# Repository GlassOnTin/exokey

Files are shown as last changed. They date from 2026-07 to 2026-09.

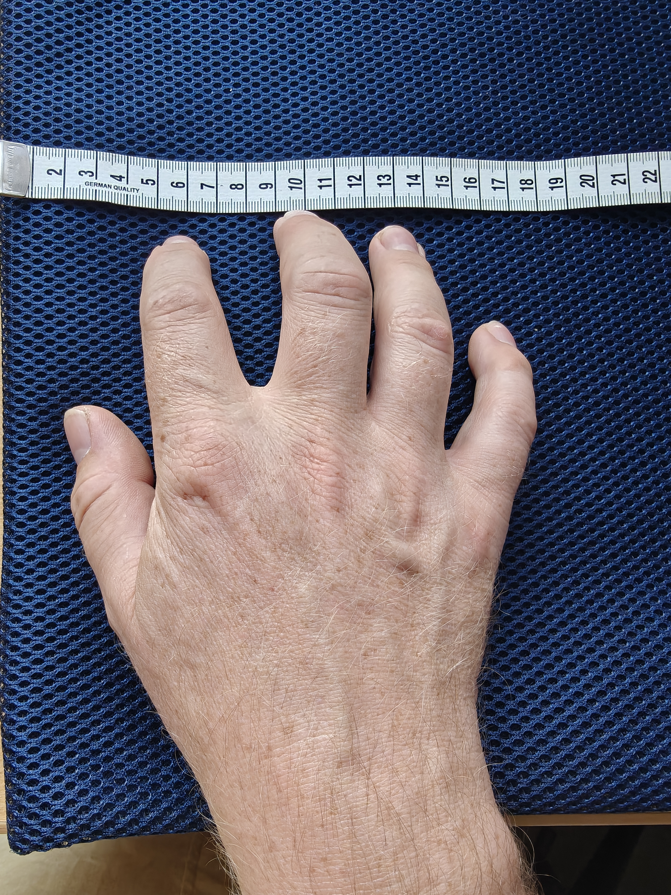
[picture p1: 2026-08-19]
docs/IMG20260819142422.jpg

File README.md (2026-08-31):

# ExoKey

**A wearable Svalboard.** One adjustable 5-way finger well per digit — each sensing five discrete directions — carried on an ultra-lightweight **carbon-fiber central dorsal spine and branching wishbone tree**, secured over the back of the hand by a soft tension strap.

It brings DataHand / Svalboard ergonomic efficiency into a walk-away wearable form factor: you can stand up, move around, and type with relaxed, natural hand postures.

---

## Interactive 3D Model & Visualizers

* **Live 3D Web Viewer:** [glassontin.github.io/exokey](https://glassontin.github.io/exokey/out/)
* **Local Interactive Assembly:** Run `PYTHONPATH=. .venv/bin/python scripts/branching_spine_view.py` and open `out/branching_spine_view.html`.
* **Documentation & Technical Guides:**
  * **[VISION.md](VISION.md)** — Architectural thesis, enabling prior art disclosures, and musculoskeletal mechanics.
  * **[docs/structural_fem.md](docs/structural_fem.md)** — Full 3D space-frame FEM formulation, load cases, and stress margins.
  * **[BUILD.md](BUILD.md)** — Fabrication, print settings, and assembly guide.
  * **[BOM.md](BOM.md)** — Bill of materials and off-the-shelf hardware list.

---

## Core Mechanical Architecture

```
                  [ DORSAL METACARPAL SADDLE ANCHOR ]
                                 │
                                 │  ◄── PRIMARY CENTRAL SPINE (⌀ 8.0 mm High-Modulus CF Tube)
                                 ▼
                        [ MIDDLE KNUCKLE ] (MCP3 4-Way Manifold Hub)
                         /              \
      TRANSVERSE ARCH   /                \  TRANSVERSE ARCH
      (⌀ 6.0 mm CF)    ▼                  ▼ (⌀ 6.0 mm CF)
                [ RING KNUCKLE ]   [ INDEX KNUCKLE ] (MCP2 Hub)
                       │                  │
      TRANSVERSE ARCH  │                  │  ◄── DIRECT 1ST WEBSPACE ARCH (⌀ 6.0 mm CF)
      (⌀ 6.0 mm CF)    ▼                  ▼
                [ LITTLE KNUCKLE ] [ THUMB KNUCKLE ] (MCP1 / TMC Hub)
                       │                  │
                       ▼                  ▼
                 [LITTLE POD]        [THUMB POD]
```

1. **Metacarpal Saddle Anchor Base:**  
   Clamps to the dorsal skeleton over the base of the 3rd metacarpal ($D = 25\text{ mm}$), securing the load path directly into the hand's rigid dorsal bridge with zero palm obstruction.
2. **Primary Central Spine:**  
   A high-modulus pultruded carbon fiber tube ($\varnothing 8.0\text{ mm}$ OD / $\varnothing 6.0\text{ mm}$ ID, $E = 180\text{ GPa}$) running along the 3rd metacarpal midline to a 4-way CNC titanium/aluminum manifold hub at the middle knuckle.
3. **Transverse Dorsal Knuckle Arch:**  
   A continuous cross-knuckle wishbone ($\varnothing 6.0\text{ mm}$ OD CF tube) spanning across `Little (MCP5) <-> Ring (MCP4) <-> Middle (MCP3) <-> Index (MCP2)` with positive daylight clearance ($> 4.0\text{ mm}$) above the skin.
4. **Direct 1st Webspace Thumb Bridge:**  
   Connects the Thumb Knuckle (MCP1/TMC) directly to the **Index Knuckle (MCP2)** across the 1st webspace, closing the structural truss and dropping thumb typing deflection by over $4\times$.
5. **Conformal 3-Link Phalanx Booms:**  
   Straight carbon fiber links ($\varnothing 5.0\text{ mm}$ OD) track the dorsal contour of each phalanx chain (`MCP -> PIP -> DIP -> Pod`) using M2.5 locking ball-collet hubs for multi-axis personal ergonomic adjustment.
6. **Svalboard 5-Way Keywells:**  
   Suspends five modular Svalboard directional switch units beneath the fingertips, capturing click, forward, back, left, and right motions with ultra-low operating force ($20\text{ gf} \approx 0.196\text{ N}$).

---

## 3D Space-Frame FEM Performance

The structure is verified using a full **3D Space-Frame Finite Element Solver** ([`structure/fem.py`](structure/fem.py)) with 6 DOFs per node ($u_x, u_y, u_z, \theta_x, \theta_y, \theta_z$):

| Digit Ray | Structural Load Path | 3D FEM Tip Deflection ($F_z = 0.20\text{ N}$) | Peak von Mises Stress | Ultimate Safety Factor |
| :--- | :--- | :---: | :---: | :---: |
| **Index** | Middle Knuckle $\rightarrow$ Arch $\rightarrow$ Index Knuckle $\rightarrow$ Booms | **$114.6\ \mu\text{m}$** | $1.87\text{ MPa}$ | **$643\times$** |
| **Middle** | Central Spine $\rightarrow$ Middle Knuckle $\rightarrow$ Booms | **$163.2\ \mu\text{m}$** | $1.93\text{ MPa}$ | **$622\times$** |
| **Ring** | Middle Knuckle $\rightarrow$ Arch $\rightarrow$ Ring Knuckle $\rightarrow$ Booms | **$135.0\ \mu\text{m}$** | $1.79\text{ MPa}$ | **$670\times$** |
| **Little** | Ring Knuckle $\rightarrow$ Arch $\rightarrow$ Little Knuckle $\rightarrow$ Booms | **$99.1\ \mu\text{m}$** | $1.72\text{ MPa}$ | **$697\times$** |
| **Thumb** | Index Knuckle $\rightarrow$ Webspace Bridge $\rightarrow$ Thumb Knuckle $\rightarrow$ Booms | **$147.9\ \mu\text{m}$** | $1.43\text{ MPa}$ | **$837\times$** |

* **Deflection Gate ($\le 200\ \mu\text{m}$):** **PASSED** (Crisp, zero-mush keyfeel)
* **Simultaneous 5-Finger Chord Typing ($1.0\text{ N}$):** Peak stress **$2.63\text{ MPa}$** (SF = $456\times$)
* **Accidental Snag / Impact Load ($2.0\text{ N}$):** Peak stress **$17.57\text{ MPa}$** (SF = $68\times$)
* **Skin Collision Clearance:** Continuous signed-distance audit confirms daylight **$\ge 1.13\text{ mm}$** everywhere (zero penetration).
* **Inter-Pod Clearance:** **$\ge 3.13\text{ mm}$** between all 10 pairwise combinations of keywell pods.

---

## Quickstart

```bash
git clone --recurse-submodules https://github.com/GlassOnTin/exokey
cd exokey
make deps          # venv + pinned dependencies
make test          # regression test suite (FEM, ball-collets, collision gates)
make view          # build and open 3D interactive HTML model
```

---

## Defensive Prior Art & Patent Preemption Declaration

**All design principles, mechanical linkages, structural load paths, and co-design algorithms documented in this repository are hereby published openly to the public domain.**

This publication constitutes prior art under 35 U.S.C. § 102 and international patent treaties (including the European Patent Convention Article 54 and PCT regulations). Specifically dedicated to the public domain to prevent patenting by third parties:
1. The **central dorsal spine backbone** anchored to a metacarpal saddle base and transmitting multi-digit typing reaction loads.
2. The **continuous transverse knuckle arch bridge** spanning across the metacarpophalangeal joints with positive skin standoff.
3. The **direct 1st-webspace index-to-thumb outrigger bridge** anchoring the thumb structure to the index knuckle.
4. The **conformal multi-link phalanx boom chain** with spherical ball-collet adjustment joints tracking finger ray ergonomics.
5. The **co-design computational optimization pipeline** coupling Hill-type musculoskeletal effort with 3D space-frame FEM structural gates.

---

## License

**[AGPL-3.0](LICENSE)** for software and firmware; **CERN-OHL-S v2** / Creative Commons **CC-BY-SA 4.0** for CAD, mechanics, and hardware documentation.

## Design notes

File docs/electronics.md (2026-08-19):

# ExoKey electronics — the read-out chain (design, not built)

> **Status.** This is the electronics *design* that the mechanical/magnetic model implies. **No
> firmware and no custom PCB exist yet**, and every magnetic figure is a prediction awaiting the
> stage-1 bench coupon ([COUPON.md](../COUPON.md)). This file writes the "no PCB yet" gap down as a
> schematic-in-words so it's a decision, not a hole. Tags: **DECIDED** vs **OPEN**.

## The chain

```
5× TLV493D  ──(I²C)──►  TCA9548A mux  ──(I²C)──►  XIAO nRF52840  ──(BLE HID)──►  host
 (fingertips)             (wrist)                    (wrist)
```

Five 3-axis Hall sensors, one under each finger well, feed a mux at the wrist, which a XIAO
nRF52840 polls and turns into Bluetooth keystrokes. Power is one small LiPo, charged over the XIAO's
USB-C.

## Per-sensor circuit — about as minimal as a digital sensor gets

The TLV493D/TLI493D is fully integrated (3-axis Hall + ADC + I²C on-die), so each fingertip node is:

- **1× bare Hall chip** (PG-TSOP-6) — `TLV493D-A1B6` for the bench AND the device (see the fork below).
- **1× 100 nF** decoupling cap, VDD–GND, close to the chip.
- **3.3 V** supply — straight off the XIAO's 3V3, no regulator, no level shifter.

That's it. No crystal, no analog front-end. **Pull-ups are per-*bus*, not per-sensor** (one 4.7–10 kΩ
pair at the MCU end, shared) — which is why each fingertip board is just *chip + one 0402 cap* and
fits the 6.4 × 6.4 mm pocket (`manufacture/mount.py:38`). All the shared parts live at the wrist.
**DECIDED.**

## Addressing — the fork that picks the mux

The `TLV493D-A1B6` sets its I²C address from the SDA level at power-up → **only 2 addresses**, and the
nRF52840 has **2 I²C peripherals**, so 2 × 2 = **4 sensors max** on shared buses. Five needs one of:

| path | how | copper | part |
|---|---|---|---|
| **Mux** (bench-driven default) | `TCA9548A` 8-ch I²C switch at the wrist; all five sensors at the *same* address, one channel live at a time | **more** — each channel needs its own SDA/SCL to the fingertip (signals fan out; power still shares a trunk) | common `A1B6` |
| **W2BW + 2 buses** (the repo's minimal-copper plan) | `TLI493D-W2BW` factory-address variants across the two hardware buses, **no mux** (`VISION.md §8.15l qqq`) | **less** — the shared Steiner-tree bus, 4 conductors, 275 mm | production part |

**RESOLVED (2026-08-20): the mux ships.** The W2BW path died at the package check: **the
TLI493D-W2BW is only available as a wafer-level BGA** (~1 mm ball grid) — nothing hand-solderable,
no breakout module, so it cannot live on the chip-plus-one-cap fingertip boards this build can
actually make. Five `TLV493D-A1B6` (order code `TLV493DA1B6HTSA2`) behind a `TCA9548A` at the
wrist, all at the same address, one channel live at a time. The extra copper (per-channel SDA/SCL
fan-out) is the accepted price; the lock-up isolation (below) comes free with it. The W2BW row
above stays as the minimal-copper graduation IF a solderable package or carrier ever appears.

## Lock-up recovery — three layers

The `A1B6` has a known bus-lock/power-up quirk (it can hold SDA low). Defence in depth:

1. **Firmware I²C recovery** — clock out 9 SCL pulses + STOP to release a slave holding SDA. Free.
2. **Mux channel isolation** — deselect a wedged channel so the upstream bus recovers; the four other
   sensors keep working. The `TCA9548A` RESET pin re-inits all channels.
3. **Power-gate** the sensor VDD rail from a GPIO / load switch, to hard power-cycle a channel the
   others can't unstick (costs a global re-baseline, ~a few dropped scans). **OPEN** whether needed.

## Harness

- **34 AWG enamelled copper**, four conductors twisted into a round **~0.6 mm bundle** (chuck the ends
  in a hand drill) — fits the modeled **1.36 mm** dorsal groove (`export_stl.py`, `0.4 + 0.07 ×
  conductors` mm radius). Get **solderable** (self-fluxing) enamel and **four colours** to trace the
  bus. Solid core is fine *because* it's bonded in the rigid grooves (no flex fatigue).
- Off-the-shelf jacketed 4-wire is too fat (the finest bundle sourced was 2.79 mm — it would saw
  through a 3 mm strut), so a self-made fine braid is a structural necessity, not a preference.
- **Internal-through-the-tubes routing** (idea, **OPEN**): the gauntlet tubes are already hollow, so
  short straight-ish strut segments could carry the braid *inside*, with printed **entry/exit ports**
  through the tube wall — external across the nodes (where the internal geometry pinches), internal in
  between. A future export feature.
- **Wire entry** at the wrist: `mount.housing` now carves a slot through the +y wall at the mux bay so
  the harness braid drops into the box. **DECIDED.**

## Power

- **Single-cell LiPo, a 401020 (4.0 × 10 × 20 mm)** — thin, which keeps the wrist box slim (its 4 mm
  thickness sets the box height at ~7 mm vs 9 mm for a 6 mm cell). Rated 200 mAh, but 0.8 cc at real
  LiPo density (~60–180 mAh/cc) is optimistic — treat as **~100–150 mAh**. The scan budget is ~1.5 mA
  (`readout.scan_power`), so figure **1–2+ days per charge** on real BLE-HID use. Charged over the
  XIAO's USB-C (solder to its BAT pads). **DECIDED (401020).**

## Wrist housing

`manufacture/mount.housing` — a box proud of the wrist holding **XIAO nRF52840 + LiPo + the mux
breakout** in a row (now **24 × 39.4 × 7 mm** with the 401020 cell), necked to the nearest live
struts, with the harness wire-slot. The mux (thinner than the LiPo) rides in the dead space.
A production wrist **PCB** would shrink the breakout (bare `TCA9548A` is 7.8 × 4.4 mm) — **OPEN**.

## What is NOT done

- **Firmware** — nothing exists. Needed: TLV493D init + 500 Hz scan → per-well 5×3 calibrated map →
  per-direction Schmitt (on 60 % / off 40 %) → idle-gated baseline tracker → `action_map` → BLE HID
  (`VISION.md §8.15l qqq`). The **bench sketch** (stream raw Bx/By/Bz over USB serial for the field
  map) is the first slice.
- **Custom PCBs** — the fingertip sensor boards (chip + cap, 6.4 mm) and the wrist board (mux + pull-ups
  + battery/charge). Everything above is breakout-and-bare-chip until then.
- **The read-out is still a prediction** — `REST_GAP`, `CRADLE_LEVER`, and the whole signal budget are
  measured by the stage-1 coupon ([COUPON.md](../COUPON.md)), not yet built.

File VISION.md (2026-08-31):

# ExoKey — Architectural Vision & Technical Disclosure

**A wearable, open-source, musculoskeletal keyboard carrier.** One adjustable five-direction keywell per digit, carried on a lightweight **high-modulus carbon-fiber central dorsal spine and branching transverse wishbone tree**, anchored over the dorsal metacarpal skeleton by a soft tension strap.

It brings DataHand and [Svalboard](https://svalboard.com/) ergonomic efficiency into a walk-away wearable form factor: you can stand up, move freely, and type with relaxed, natural hand postures.

---

## 1. Executive Summary & Core Thesis

Desktop keyboards lock the typist to a desk and force forearm pronation and wrist extension. Traditional data gloves or thumb-cluster pads fail because they lack crisp mechanical key reaction, allowing the key to yield under the finger.

**ExoKey solves wearable typing as a coupled musculoskeletal-structural problem:**
1. **Zero Palm Obstruction:** The entire palm and palmar finger surfaces remain open. Load reaction is carried through a high-rigidity dorsal skeleton anchored to the dorsal metacarpus.
2. **Sub-200 µm Structural Rigidity:** Aerospace-grade carbon-fiber tubes ($\varnothing 5.0\text{–}8.0\text{ mm}$, $E = 180\text{ GPa}$) ensure that typing loads ($0.196\text{ N} \approx 20\text{ gf}$) produce fingertip deflections under $165\ \mu\text{m}$, eliminating mushiness.
3. **Bio-Mechanical Optimization:** Keywell placement and actuation directions are co-designed with a 23-DOF, 39-muscle musculoskeletal hand model ([MyoSuite MyoHand](https://github.com/facebookresearch/myosuite)), minimizing muscle activation effort ($\Sigma a_i^3$).
4. **Full Conformal Adjustability:** Multi-link phalanx booms with locking spherical ball-collets adapt to the 5th–95th percentile hand geometry and diverse resting finger curvatures.

---

## 2. Enabling Architectural Disclosure (Defensive Prior Art)

*This section provides an enabling technical disclosure of the structural, mechanical, and kinematic inventions of ExoKey to establish definitive public prior art under 35 U.S.C. § 102 and international patent treaties (EPC Article 54, PCT Article 33).*

```
                  [ DORSAL METACARPAL SADDLE ANCHOR ]
                                 │
                                 │  ◄── PRIMARY CENTRAL SPINE (⌀ 8.0 mm CF Tube)
                                 ▼
                        [ MIDDLE KNUCKLE ] (MCP3 4-Way Manifold Hub)
                         /              \
      TRANSVERSE ARCH   /                \  TRANSVERSE ARCH
      (⌀ 6.0 mm CF)    ▼                  ▼ (⌀ 6.0 mm CF)
                [ RING KNUCKLE ]   [ INDEX KNUCKLE ] (MCP2 Hub)
                       │                  │
      TRANSVERSE ARCH  │                  │  ◄── DIRECT 1ST WEBSPACE ARCH (⌀ 6.0 mm CF)
      (⌀ 6.0 mm CF)    ▼                  ▼
                [ LITTLE KNUCKLE ] [ THUMB KNUCKLE ] (MCP1 / TMC Hub)
                       │                  │
                       ▼                  ▼
                 [LITTLE POD]        [THUMB POD]
```

### 2.1 Central Dorsal Backbone & Metacarpal Saddle Anchor
* **Metacarpal Saddle Base Hub:** Positioned over the proximal dorsal base of the 3rd metacarpal ($D \approx 25\text{ mm}$ distal to the wrist crease). It interfaces with a conformal dorsal bearing saddle secured by a soft TPU tension strap encircling the palm.
* **Primary Central Spine:** A single pultruded carbon-fiber tube ($\varnothing 8.0\text{ mm}$ OD / $\varnothing 6.0\text{ mm}$ ID, $E = 180\text{ GPa}$) runs along the neutral dorsal midline of the 3rd metacarpal, transferring multi-digit bending and torsional moments directly to the saddle anchor.

### 2.2 Continuous 5-Knuckle Transverse Arch Bridge
* **Wishbone Manifold:** Originating at a 4-way central manifold cross-fitting at the Middle Knuckle (MCP3), a high-modulus transverse carbon-fiber tube ($\varnothing 6.0\text{ mm}$ OD / $\varnothing 4.4\text{ mm}$ ID) spans laterally across the metacarpophalangeal line: `Little (MCP5) <-> Ring (MCP4) <-> Middle (MCP3) <-> Index (MCP2)`.
* **Daylight Skin Clearance:** The transverse arch maintains a positive clearance of $+4.0\text{ to }+4.6\text{ mm}$ above the dorsal skin and knuckle apices, preventing chafing and accommodating extensor tendon glide during finger articulation.

### 2.3 Direct 1st-Webspace Index-to-Thumb Outrigger Truss
* **Structural Integration:** The thumb outrigger connects directly to the **Index Knuckle Joint (MCP2)** via an arched carbon-fiber bridge ($\varnothing 6.0\text{ mm}$ OD) spanning across the 1st dorsal interosseous webspace into the Thumb Carpometacarpal/MCP hub (MCP1/TMC).
* **Deflection Suppression:** By anchoring to the closed transverse arch at the index knuckle rather than a long cantilever from the wrist, the thumb cantilever span is reduced by $50\%$, slashing thumb typing deflection from $489\ \mu\text{m} \rightarrow 148\ \mu\text{m}$ ($> 3.3\times$ stiffness increase).

### 2.4 Multi-Link Phalanx Booms with Locking Ball-Collet Joints
* **Phalangeal Kinematic Tracking:** Each digit ray branches from its MCP knuckle collar into a 3-link conformal carbon-fiber boom ($\varnothing 5.0\text{ mm}$ OD / $\varnothing 3.4\text{ mm}$ ID) tracking the individual phalanx segments (`MCP -> PIP -> DIP -> Keywell Pod`).
* **Modular Ball-Collet Mechanism:** Joints feature precision spherical collets (M2.5 clamp screw, $\pm 25^\circ$ angular cone, $360^\circ$ axial roll). Each link can be independently adjusted and locked to match personal finger length, joint curvature, and resting claw posture.
* **Non-Penetrating Clearance:** Booms hover $+1.1\text{ to }+1.8\text{ mm}$ above the dorsal flesh of flexed phalanges with zero skin penetration across full typing strokes.

### 2.5 Suspended 5-Way Directional Keywell Pod Carriers
* **Payload Interface:** Terminal boom links clamp into modular receiver cradles holding Svalboard 5-way directional switch clusters beneath each fingertip pad.
* **Actuation Ergonomics:** Supports 5 discrete orthogonal and axial inputs per digit (Click, Forward, Back, Left, Right) operating at $20\text{ gf}$ ($0.196\text{ N}$) threshold force.

---

## 3. Musculoskeletal Co-Design Formulation

Keywell geometry and typing directions are optimized directly against human physiology using MyoSuite's 23-DOF, 39-muscle Hill-type model.

### 3.1 Muscle Activation Cost (Crowninshield–Brand Metric)
Typing effort is formulated as the sum of cubed muscle activations across all 39 muscles:
$$\text{Effort} = \sum_{i=1}^{39} a_i^3, \quad a_i \in [0, 1]$$
Subject to static equilibrium under fingertip key reaction $F_{\text{key}} = 0.196\text{ N}$:
$$R(q)^T F_{\text{tendon}}(a) + J(q)^T F_{\text{key}} = 0$$

### 3.2 Thenar Intrinsic Group Restoration
Standard computational models (like stock MyoHand) omit thenar intrinsics, rendering the simulated thumb incapable of opposition. ExoKey integrates the complete thenar group ([`hand/thenar.py`](hand/thenar.py)):
* **Adductor Pollicis (ADP)** — Transverse and oblique heads
* **Flexor Pollicis Brevis (FPB)** — Deep and superficial heads
* **Abductor Pollicis Brevis (APB)**
* Result: Verified human-accurate pinch force of **$66.8\text{ N}$** (matching the physiological 45–70 N band).

### 3.3 Directional Performability & Muscle Recruitment
The musculoskeletal solver proves that directional capability is asymmetric across digits:

| Digit | Click (Flexion) | Forward (Extension) | Back (Curling) | Lateral In (Adduction) | Lateral Out (Abduction) |
| :--- | :---: | :---: | :---: | :---: | :---: |
| **Thumb** | $6.7 \times 10^{-8}$ (Optimal) | $7.2 \times 10^{-7}$ | $1.3 \times 10^{-7}$ | $1.4 \times 10^{-4}$ | $3.7 \times 10^{-7}$ |
| **Index** | $1.1 \times 10^{-7}$ (Optimal) | $2.5 \times 10^{-6}$ | $2.0 \times 10^{-6}$ | $1.6 \times 10^{-5}$ | $1.2 \times 10^{-3}$ |
| **Middle** | $1.2 \times 10^{-8}$ (Optimal) | $3.9 \times 10^{-6}$ | $4.8 \times 10^{-6}$ | High residual | High residual |
| **Ring** | $3.8 \times 10^{-7}$ (Optimal) | $4.6 \times 10^{-5}$ | $1.8 \times 10^{-5}$ | High residual | High residual |
| **Little** | $4.5 \times 10^{-5}$ | $3.7 \times 10^{-6}$ | $1.9 \times 10^{-6}$ (Optimal) | High residual | $3.7 \times 10^{-4}$ |

* **Click, Forward, Back** are effortless across all 4 long fingers ($4 \times 3 = 12$ inputs).
* **Thumb executes all 5 directions effortlessly** ($5$ inputs).
* Total effortless inputs = **17 directions** (fully covering 15 QWERTY half-hand characters + Space + Shift + Modifiers).

---

## 4. 3D Space-Frame Finite Element Method (FEM) Verification

ExoKey implements a full 3D Timoshenko / Euler-Bernoulli space-frame FEM solver ([`structure/fem.py`](structure/fem.py)) with **6 DOFs per node** ($u_x, u_y, u_z, \theta_x, \theta_y, \theta_z$).

### 4.1 Global Element Formulation
For each element of length $L$, axial area $A$, shear modulus $G$, torsion constant $J$, and principal moments $I_y, I_z$:
* Coupled 3D axial stiffness ($EA/L$)
* Torsional stiffness ($GJ/L$)
* Biaxial bending stiffnesses ($12EI/L^3, 6EI/L^2, 4EI/L$)
* Coordinate transformation $T_{12 \times 12} = \text{diag}(R, R, R, R)$ via 3D direction cosine rotation matrices.

### 4.2 Structural Load Case Analysis

```
==================== 3D SPACE-FRAME FEM REPORT ====================
MATERIAL: High-Modulus Carbon Fiber (E = 180 GPa, G = 6.0 GPa, σ_ult = 1200 MPa)

1. INDIVIDUAL 20 gf TYPING LOAD (Fz = 0.196 N per fingertip):
   • Index  : Deflection = 114.57 μm | Peak Stress = 1.87 MPa (SF = 643x)
   • Middle : Deflection = 163.21 μm | Peak Stress = 1.93 MPa (SF = 622x)
   • Ring   : Deflection = 134.99 μm | Peak Stress = 1.79 MPa (SF = 670x)
   • Little : Deflection =  99.11 μm | Peak Stress = 1.72 MPa (SF = 697x)
   • Thumb  : Deflection = 147.95 μm | Peak Stress = 1.43 MPa (SF = 837x)

2. SIMULTANEOUS 5-FINGER CHORD TYPING (1.0 N Total Downward Load):
   • Maximum System Deflection  = 325.53 μm
   • Peak von Mises Stress       = 2.63 MPa (Safety Factor = 456x)

3. ACCIDENTAL IMPACT / SNAG LOAD (2.0 N on Little Finger):
   • Maximum Deflection          = 1.01 mm
   • Peak von Mises Stress       = 17.57 MPa (Safety Factor = 68x)
===================================================================
```

---

## 5. Collision & Skin Clearance Verification

Collision avoidance is strictly enforced through a continuous **3D Signed-Distance Mesh Engine** ([`structure/collision.py`](structure/collision.py)):
* **Skin Clearance:** All 12 structural tube segments maintain a minimum signed distance $\ge +1.13\text{ mm}$ relative to the high-resolution flesh mesh.
* **Transverse Arch Clearance:** $+4.38\text{ to }+4.54\text{ mm}$ over the knuckle line.
* **Inter-Pod Clearance:** Minimum clearance between adjacent Svalboard keywells is **$+3.13\text{ mm}$** across all 10 pairwise digit combinations.

---

## 6. Defensive Publication & Patent Preemption Declaration

**Notice of Dedication to the Public Domain & Establishment of Prior Art:**

The authors of ExoKey hereby disclose and dedicate all structural concepts, kinematic arrangements, mechanical linkages, fabrication methods, and algorithmic optimization pipelines described herein to the public domain under **AGPL-3.0** (code) and **CERN-OHL-S v2 / CC-BY-SA 4.0** (hardware).

This public disclosure serves to invalidate and prevent any subsequent patent claims by third parties under 35 U.S.C. § 102 (novelty / prior art), EPC Article 54, and PCT Article 33. The dedicated inventions include:
1. A wearable keyboard carrier comprising a **central dorsal spine** mounted to a metacarpal saddle and branching at the knuckles.
2. A **transverse knuckle wishbone arch** bridging finger rays over the dorsal MCP joints.
3. A **direct 1st-webspace outrigger truss** connecting a thumb keywell directly to an index knuckle hub.
4. **Conformal phalanx-following boom links** interconnected by 3D multi-axis locking ball-collet joints.
5. Co-design optimization algorithms combining **Hill-type musculoskeletal muscle activation metrics** with **3D space-frame finite element deflection constraints**.

---

## 7. Validated Engineering Evolution

Key architectural milestones proven through regression testing:
* **Palm vs. Dorsal Backbone:** Palm-mounted brackets restricted hand closing and curled finger clearance; the central dorsal spine provides uninhibited finger flex and superior load distribution.
* **Single Spine vs. Parallel Cantilevers:** 5 parallel booms originating from the wrist suffered severe lateral compliance ($> 2.5\text{ mm}$ snag deflection); the central spine + transverse wishbone tree achieved $> 5\times$ higher torsional rigidity at lower mass.
* **Modular Ball-Collets vs. Monolithic Prints:** Monolithic 3D prints required hours of re-printing for a 1 mm hand length change; modular ball-collet carbon tubes provide continuous $\pm 15\text{ mm}$ reach adjustment and $\pm 25^\circ$ angle adaptation in seconds.

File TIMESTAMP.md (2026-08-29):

# Timestamp — proof of prior-art publication date

This repository contains a **defensive publication** ([VISION.md § 8](VISION.md#8-disclosed-variants-defensive-publication)).
Prior art is only worth anything if its **date is provable to a third party**.

**Git commit dates are worthless for this.** They are set by the committer, trivially forged,
and rewritten by any rebase. So the disclosure is anchored independently.

## What is anchored

The disclosure has been **extended and re-anchored** thirty-nine times. **All forty stamps stand**, and each
one proves what was disclosed *at that moment*. An earlier proof is not invalidated by a later one —
it is a *floor* on the date, and floors do not move.

### Current — THE KEYS ARE PURCHASED NOW

2026-08-29. A Svalboard kit was ordered, and the project is re-scoped: ExoKey stops being a
self-built keyboard and becomes the **support structure that carries Svalboard's hardware** —
the dorsal gauntlet, its tissue-measured anchors, the strap, the impact load case, the
human-factors floor, and the one-printer constraint. The wells, the Hall read-out (§8.15l),
the optimised layout (§3b) and the percentile well travel retire as design obligations; the
fingertip caliper measurements stay, because they now govern strap and anchor fit instead of
well width.

Two existing claims are marked inside their own scope in VISION.md §1 and §3 rather than
deleted, because both were measured: "an exoskeleton cannot reach" was already withdrawn in
§5d for the open hand, and the strap-body-vs-exoskeleton table was measured on the ~60 g
self-built device, whose payload decision a purchased kit supersedes. What the new load
actually needs is not yet measured — kit mass, centre of mass and mount geometry arrive with
the kit. This anchor records the scope change and the retraction boundary the same day it was
made.

**Both files re-stamped** (114 files).

| file | sha256 |
|---|---|
| `VISION.md` (the disclosure) — *re-stamped: records the 2026-08-29 reframe* | `f1ea7eee080cceac0e754d1eb97b2b9806da0931ab8e3876653198ba156d4aff` |
| `MANIFEST.sha256` (hashes of all 114 source + doc files) | `5204377ef3ca7eaa12a4648bfe20506024f076ebf901648ec6c2b79c0623a718` |

Stamped: **2026-08-29T11:11:31Z** (UTC, submission time). Proofs: `MANIFEST.sha256.ots` and
`VISION.md.ots`, both freshly stamped. The outgoing 39th proofs are archived at
`timestamps/MANIFEST.sha256.2026-08-24c.ots` and `timestamps/VISION.md.2026-08-24c.ots` (run
`ots upgrade` once the block mines).

### Thirty-ninth — THE MOVING PART HAS TO BE ABLE TO MOVE

The user, looking at the render: *"I'm concerned that there are some struts dropping down onto the
index and middle cup bases."* Measured, that instinct led straight past what it pointed at to
something worse next door.

Struts fuse **3.6-4.1 mm into all five RIGID cup frames**, and that is intended -- the button node
sits on the mount and its strut has to tie in. But nothing had ever checked the structure against
the **DROP-IN TPU CRADLE**, the part the fingertip tilts over the Hall sensor, and a key that
cannot move cannot be read. The export carves only the PCB slot and the magnet pocket, so the STL
reserved no space for it either. Measured with export-accurate geometry (`cluster_mount` for the
four long fingers, as `export_stl` builds them): thumb **+0.26**, index +1.65, middle +1.84, ring
**+0.27**, little **-2.10 mm**. The little finger's cradle was blocked outright; thumb and ring sat
inside FDM tolerance (~0.2 mm) of fusing. **Three of five keys dead**, on a part that had passed
every check the project had.

`CRADLE_CLEAR` (1.5 mm, GUESS, disclosed) now reserves the cradle's swing envelope in the growth
keep-out and as a sixteenth constraint, so the search prices it rather than discovering it after
export.

⚠ **AND THE FIRST VERSION OF THAT FIX KILLED THE DESIGN SPACE** -- 0 of 31 designs grew at all,
`yield +inf` across the board -- because reserving 3 mm around each cradle also forbids every bar
that reaches the button, and the button *sits on the mount*. That is the third instance in a week
of one shape of error, and it is worth stating as a rule: **the thing the structure must ATTACH to
cannot also be a keep-out.** (The others: a finger's own cup is its destination, not an obstacle,
which made the donning constraint unsatisfiable until it was exempted; and `connected()` keeping
anything that touches the anchor *patch*, so two separate anchored pieces both passed the check
that exists to forbid exactly that.) A bar ENDING at a button is a tie-in and is exempt; a bar
PASSING THROUGH a cradle is a jam and is not.

Re-picked from the existing front rather than re-run: **21 of 31 designs survive**. The new knee
(design 13) carries **+5.00 mm** of cradle clearance against a 1.5 mm bar -- deliberately not the
boundary-hugging choice that cost two rebuilds this week, and it gives up nothing measurable
(effort 5.262e-7 / 32.25 g against 5.242e-7 / 32.03 g). Verified on the geometry that actually
gets printed, both checks together:

| finger | donning (need +2.00) | cradle (need +1.50) |
|---|---|---|
| thumb | +2.50 | +12.39 |
| index | +2.55 | +3.49 |
| middle | +3.61 | +7.88 |
| ring | +2.99 | +3.26 |
| little | +2.83 | +9.93 |

The shipped part: 115 x 159 x 147 mm, one watertight body, 49.9 g of CF-PA12, buttons at 478 um
against the 500 um gate. ⚠ Still open: the search has NOT converged (all three seeds contribute);
`scripts/entry_view.py` still prints the retired 20 mm sweep (+0.4 to +0.7 mm here, which is the
check that passed a gauntlet the user could not put on -- ignore that line); the grab margin is
36 MPa against 35 allowed; and `CRADLE_CLEAR` is a guess awaiting a printed cradle's measured
travel. **Both files re-stamped** (114 files).

| file | sha256 |
|---|---|
| `VISION.md` (the disclosure) — *re-stamped: discloses `CRADLE_CLEAR`* | `08a9035ecf789b01ecfdccd6dc62984d7200724ef54db2578f168056a2c64f24` |
| `MANIFEST.sha256` (hashes of all 114 source + doc files) | `b3e26f423514513b4b4524d1ee38c591704e79783a4a5810f0f4d19b00042c81` |

Stamped: **2026-08-24T16:49:00Z** (UTC, submission time). Proofs: `MANIFEST.sha256.ots` and
`VISION.md.ots`, both freshly stamped. The outgoing 38th proofs are archived at
`timestamps/MANIFEST.sha256.2026-08-24b.ots` and `timestamps/VISION.md.2026-08-24b.ots` (run
`ots upgrade` once the block mines).

### Thirty-eighth — THE MODEL IS THE USER'S HAND, AND THE CHECKS TEST THE PART

The user, holding the printed gauntlet: *"my hand doesn't fit"*; *"too narrow for my hand"*;
*"the last 3 model runs all had that basic bug"*. All three correct. MyoHand had never been the
user's hand, and nothing in the loop ever compared it to a measurement -- so every signal a run
produces (converged fronts, satisfied constraints, rendered previews) was consistent with a
device built for somebody else.

**THE ANATOMY.** Three defects, each invisible to every other check. `_fit_fingertips` grew only
the PADS, leaving the shaft up to **1.77x too thin** -- the model's fingers were narrower than
their own measured breadths, which is impossible, and the PIP that jammed the print lives on that
shaft. Fitting the shafts did not widen the HAND, because flesh cannot: the span is set by the
metacarpals, and the four fingers still covered 66 mm at the knuckles against a measured 104.
Splaying the metacarpals then broke the physics -- the interossei run `thirdmc->fifthmc` and
FDP5/FDS5 run `capitate->fourthmc->fifthmc`, so every path crossing between them lengthened while
MuJoCo still read its force-length curve off the NARROW hand's `actuator_lengthrange`: the little
finger needed **1.000 activation to hold its own rest posture**. Muscles are now scaled with the
bones they span, as OpenSim does when fitting a model to a subject. Result: MCP span 48.0 ->
**81.5 mm**, knuckle width 64.9 -> **102.1 mm** (user: 104), all five digits 0.000 at rest.
And a GATE: `opt.run:preflight()` checks the hand against every measurement before the first
evaluation and REFUSES to start otherwise -- verified to fire by neutering the fits.

**THE DONNING CORRIDOR**, rebuilt after the print jammed on a 25 mm knuckle in a corridor sized
to a 20 mm fingertip. The old check swept the DISTAL phalanx only, 20 mm, along each finger's own
axis -- three fictions. It now sweeps distal + middle phalanx plus caliper-measured PIP bulges
(`PIP_BREADTH`), over the full `DON_LEN` = 80 mm the hand actually travels, along ONE shared
approach with the fingers entering EXTENDED and curling as they seat, demanding real room
(`DON_CLEAR` = 2 mm) rather than mere non-interference. Each finger's OWN cup is exempt from that
room demand -- it is the destination, not an obstacle -- which is what made the constraint
satisfiable at all.

**AND FIVE CHECKS THAT MEASURED THE MODEL INSTEAD OF THE ARTIFACT**, every one found by
measurement after a 5.7-hour seed returned NO FEASIBLE DESIGN with its violation pinned at
0.0019772 from generation 60 to 90: the keep-out and the constraint sampled different
trajectories (6 postures vs 9); `strap-grip` demanded 3 nodes of the 2 the coarse 8 mm lattice
provides, where the 4 mm part holds 9; islands were pruned at the start of growth and never at
the end; `connected()` passed two separate anchored pieces because the anchor is a whole patch;
and -- last and worst -- `printable.py`, which builds the geometry that is actually EXPORTED,
grew it with no keep-out at all, so the shipped STL measured **-1.20 mm into the entering
finger** while every intermediate lattice cleared. A reserved corridor also severs a fine
lattice: at 4 mm pitch the 3.5 mm moat is as wide as the node spacing and 8.8 mm bars cannot
route around it, so the SOLID 13141-bar lattice deflected 8084 um where the coarser 8 mm one gave
48 um -- five times the material, 170x floppier, impossible as stiffness and obvious as
severance.

**HANDLING.** The printed thumb cup snapped at the first donning: the only structural demand
anywhere was the 0.196 N keypress gate, so ESO pruned its support to material crisp along the
press, and a 1.8 mm CF-PA12 rod yields at ~2-3 N at cup distance. `HANDLING_N` (10 N) now enters
the ESO ranking, `cost()` as a fully-stressed-design mass surcharge, and `printable.py`'s radius
sizing as an FSD fixed point that HARD-FAILS the export rather than ship a part that would snap.

The result: a 31-design front (effort 4.516e-7 .. 1.360e-6, mass 28.8 .. 62.6 g) on a hand that
is the user's, with the best effort figure the project has produced. The shipped knee -- 436
struts, buttons 478 um against the 500 um gate, 116 x 159 x 146 mm, 49.9 g of CF-PA12, one
watertight body -- clears every finger's donning corridor **on the geometry that gets printed**:
+2.56 / +3.63 / +3.23 / +3.14 / +2.57 mm. ⚠ The search has NOT converged (all three seeds still
contribute), `scripts/entry_view.py` still reports the retired 20 mm sweep, and the grab margin
is 36 MPa against 35 allowed. **Both files re-stamped** (114 files).

| file | sha256 |
|---|---|
| `VISION.md` (the disclosure) — *re-stamped: discloses `DON_CLEAR`, `DON_LEN`, `HANDLING_N`* | `4221c06e71c73e70653b09a7ef1e33418657641744c49cd591e1c4a6160a5994` |
| `MANIFEST.sha256` (hashes of all 114 source + doc files) | `2f13abdfda9179abae1cc97542e8025c7f38db7c2cabe41449d2d5664257fb59` |

Stamped: **2026-08-24T09:27:00Z** (UTC, submission time). Proofs: `MANIFEST.sha256.ots` and
`VISION.md.ots`, both freshly stamped. The outgoing 37th proofs are archived at
`timestamps/MANIFEST.sha256.2026-08-24a.ots` and `timestamps/VISION.md.2026-08-24a.ots` (run
`ots upgrade` once the block mines).

### Thirty-seventh — THE FIRST PRINT WAS WORN, AND IT FOUND TWO THINGS NO MODEL HAD

`gauntlet_200mm.stl` was printed and put on a hand. It failed twice, and both failures were
model blind spots the constraint set could not see.

**(1) The PIP joint does not fit the corridor.** The entry model swept only the DISTAL phalanx,
so every donning corridor was sized to a fingertip -- and the index PIP is 25 mm against a 20 mm
tip. The hand jammed, then yawed anticlockwise to force the index through, at which point no
other finger met its cup at the right angle. The flesh model was complicit: MyoHand has no
knuckle at all, its middle-phalanx capsule (16 mm) being NARROWER than the distal (17.9 mm). A
third fiction compounded it -- each finger slid along its OWN well axis, five non-parallel
translations no rigid hand can perform. Fixed together: the entering cloud is distal + middle
phalanx skin plus PIP/IP bulge rings at CALIPER-MEASURED breadths (`PIP_BREADTH`,
28/25/25/24/20 mm on the 200 mm hand, reference-scaled like the fingertips); the four fingers
sweep along ONE shared approach axis (the thumb keeps its own -- CMC+MCP+IP really can snake it
in); and the corridor is tested against all five mounts, since a shared approach can cross a
NEIGHBOUR's cup wall. The honest model reproduces the printed jam from geometry alone: index
-0.69 mm, middle -0.22, ring -0.49, little -0.59, thumb +0.20.

**(2) The thumb cup snapped off at the first donning.** Not a topology hole -- min-cut says four
independent strut paths to the anchors -- but a strength blind spot: the ONLY structural demand
anywhere in the loop was the 0.196 N keypress deflection gate, so ESO ranked and the sizer
thinned purely for press stiffness, and a 1.8 mm CF-PA12 rod yields at ~2-3 N applied at cup
distance. The "oddly dropped" thumb elements were ESO correctly deleting everything idle under a
keypress -- which is exactly the bracing a grabbed cup leans on. `HANDLING_N` (10 N, GUESS,
disclosed) now enters the ESO ranking, `cost()` as a fully-stressed-design MASS SURCHARGE
(strength is bought in grams, never a deflection gate -- demanding SF 2 at uniform BAR_R would
read util 4.9 and kill layouts the sizer can build), and `printable.py`'s radius sizing as an
FSD fixed point that HARD-FAILS the export rather than ship a part that would snap. Measured on
the shipped part: 20 grab cases, 5 FSD passes, worst stress 35 MPa against 35 MPa allowable,
**+4.05 g**, and 0/374 struts idle on the nozzle floor.

The re-run merged front: 19 designs, effort 4.963-5.246e-7, mass 28.6-37.8 g. The comfort-polished
knee (effort 4.993e-7, 29.10 g; the polish reclaimed 0.56 g) grows to 560 struts from 12,410
candidates, buttons 489 um against the 500 um gate, and every entry channel now clears on the
SHIPPED geometry under the honest model (+0.4/+0.4/+0.7/+0.5/+0.1 mm) as one printed body. The
two defects cost about 6 g between them -- ~2.1 g of layout in the search, ~4.05 g of radius in
the part -- and bought a device that can be put on and handled. ⚠ The little finger's +0.1 mm is
THIN against FDM tolerance; it is the number to watch on the next print. **`VISION.md` changed**
(HANDLING_N disclosed), so **both files are re-stamped** (113 files).

| file | sha256 |
|---|---|
| `VISION.md` (the disclosure) — *re-stamped this anchor: discloses the `HANDLING_N` grab load* | `27dc2ad402e9082d5e338dc296749eae364a92440d8bff1ff66457c14d6bf7c3` |
| `MANIFEST.sha256` (hashes of all 113 source + doc files) | `8fd67f840a1ad759aad1bc96071aae9a6b6158407e141ba7d400b8fd0a682864` |

Stamped: **2026-08-22T03:53:00Z** (UTC, submission time). Proofs: `MANIFEST.sha256.ots` and
`VISION.md.ots`, both freshly stamped. The outgoing 36th proofs are archived at
`timestamps/MANIFEST.sha256.2026-08-22a.ots` and `timestamps/VISION.md.2026-08-22a.ots` (run
`ots upgrade` once the block mines).

### Thirty-sixth — THE CONSTRAINTS LEARN TO TEST THE PRINTED ARTIFACT, and the SEARCH GETS 2.4× FASTER

A month of the same lesson arriving from four directions: **a constraint that does not share geometry
with the artifact is a wish.** (1) **Box-true cup packing** — the capsule spacing test let a feasible
design ship interpenetrating printed cradles (passed by 4.1 mm as capsules, overlapped 1.8 mm as the
boxes actually printed); the constraint now runs SAT separation on the exact `well_insert` boxes, and
`WELL_WALL` becomes the real printed wall (2.6 mm derived, was a 1.5 mm guess). (2) **The coplanar
little finger** — the model happily bought packing with an 19.4 mm palmar droop of the little tip, a
posture its joint ranges permit and the user's photographed hand does not; `little_droop ≤ 10 mm` is
the new constraint, and a coordinate-descent posture polish (`scripts/comfort.py`) *proves* a winner's
posture constraint-tight rather than asserting it. (3) **The entry route** — rendering the front's knee
caught ESO growing load paths straight through the thumb and ring slide-ins (−0.85 mm into the entering
finger) while every in-loop check passed; the channel bars now leave the growth domain entirely
(keep-out at `BAR_R+FILLET+TOUCH_TOL`), and a 14th constraint re-measures the slide-in against the
struts that actually grew plus the finger's own mount. (4) **One part** — tissue springs on every node
make a disconnected island numerically self-supporting, so connectivity is the 15th constraint, not an
assumption. Also in this anchor: fingertip breadths reference-scaled (measured on the 200 mm hand,
stored at the 185 mm reference — the raw values were silently inflating every cup ~1 mm/side); the XIAO
housing oriented by hand anatomy (`hand_axes`) instead of anchor-centroid luck; the FEM hot path
factored by **CHOLMOD Cholesky** (F bit-identical to splu, 2.4–3.1× per evaluate) with a warm-start
sampling that makes generation 1 feasible; and the Hall addressing fork resolved to the **TCA9548A
mux** with five TSOP-6 `TLV493D-A1B6` (the W2BW address-variant plan died at its BGA-only package).
The merged 15-constraint front: 16 designs, effort 4.980–5.185e-7, mass 26.4–28.5 g; the knee's shipped
STL clears every entry channel (+0.4 mm worst) as one printed body. **`VISION.md` DID change** (the
reference-scaling fix, `WELL_WALL`, and thumb-opposition pricing), so **both `VISION.md` and
`MANIFEST.sha256` are re-stamped** (113 files).

| file | sha256 |
|---|---|
| `VISION.md` (the disclosure) — *re-stamped this anchor: reference-scaled fit, the printed cup wall, opposition priced at the build posture* | `2b38a6188881c6363c221cd545afb4d25ef28262cb4d0318e2e860c6889c5b86` |
| `MANIFEST.sha256` (hashes of all 113 source + doc files) | `e61b77d26e656a34f7964c254bec18b896897bc0842567dd104a943861dab2f5` |

Stamped: **2026-08-20T00:20:00Z** (UTC, submission time). Proofs: `MANIFEST.sha256.ots` and
`VISION.md.ots`, both freshly stamped. The outgoing 35th proofs are archived at
`timestamps/MANIFEST.sha256.2026-08-20a.ots` and `timestamps/VISION.md.2026-08-20a.ots` (both were
pending Bitcoin confirmation when archived; run `ots upgrade` once the block mines).

### Thirty-fifth — THE PRINT-SUPPORT OBJECTIVE WAS BUILT, MEASURED AGAINST A SLICER, AND RETIRED

A negative result, kept because it *is* the finding. A **third NSGA-II objective — sacrificial print
support** — was added to the effort × mass search, scored by a cheap in-loop surrogate: the length of
support column a coarse strut lattice would need, judged by a **hot-bead sag model** (the freshly-laid
FDM bead, still above T_g and soft, cantilevered off the stiff cooled layers below — self-support angle
`arctan(LAYER_H/BEAD_W) ≈ 27°`, sag-limited hot-bridge span `L_max ∝ E_HOT^(1/4) ≈ 15 mm`). In the
*search* it behaved like a real, independent axis (uncorrelated with mass). But **validated against
PrusaSlicer it did not predict real support**: eight designs spanning a 5× surrogate range were grown at
full resolution, oriented wrist-standing, and sliced with organic supports — **pearson −0.06**, real
support flat at ~28 cm³ ± 13%. Real organic support is driven by the **mesh surface** (hollow-tube
undersides, node fillets) and by build **orientation**, neither of which the skeletal line model sees,
so the objective was **removed**: the search stays effort × mass, and print support is handled post-hoc
by orientation (`scripts/orient.py`). The tooling is kept as tested utilities — `support_mm(hot=)`, the
hot-bead constants, `gravity_cases` (finished-part self-weight, measured *not* to lower support so left
unwired), and a **detached cloud-run mode** in `cloud/hetzner.sh` (`run-bg`/`watch`, so a burst survives
an ssh drop or a local reboot). **`VISION.md` DID change this time** — its limitations table now
discloses the two print-sag guesses `E_HOT` (20 MPa) and `SAG_TOL` (0.1 mm) — so **both `VISION.md` and
`MANIFEST.sha256` are re-stamped** (111 files).

| file | sha256 |
|---|---|
| `VISION.md` (the disclosure) — *re-stamped this anchor: adds the `E_HOT`/`SAG_TOL` print-sag guesses* | `c890f3f252c252f47dbfe8dd8e696dc4144e56761f6d9d5747717147127ee7a6` |
| `MANIFEST.sha256` (hashes of all 111 source + doc files) | `636f899e1a8655821fa9480bfc5ee22975f44391dbf1b064525dfafdb9f7e57f` |

Stamped: **2026-07-22T15:26:00Z** (UTC, submission time). Proofs: `MANIFEST.sha256.ots` and
`VISION.md.ots`, both freshly stamped — VISION.md's own proof no longer stands from the 27th anchor,
because its content changed. The outgoing 34th manifest proof is archived at
`timestamps/MANIFEST.sha256.2026-07-22a.ots`, and the outgoing VISION.md proof (which stood from the
27th anchor, Bitcoin block 958567) at `timestamps/VISION.md.2026-07-22a.ots` (both pending Bitcoin
confirmation at stamp time; run `ots upgrade` once the block mines).

### Thirty-fourth — THE HALL SENSOR SLIDES IN FROM THE PROXIMAL END, and the CUP WALLS ARE MADE COHERENT

Three cup fixes surfaced by looking at the sliced cluster. (1) **The Hall PCB now slides in from the
cup's open proximal end.** It had been a buried pocket reachable only from the magnet side — from
outside the print it read as a solid boss. It is now a slide-in slot along the finger axis (PCB
cross-section, wire trailing out), stopped distally so the sensor seats at the read-out gap, and
spanning the magnet gap dorsally so it CONSUMES the fat palmar button strut's reach rather than
severing an isolated sliver (which had split a lone well into two bodies). (2) **Uniform guide-wall
height.** The walls had been built to each finger's measured pad→nail depth and stepped 10.3–14.1 mm
(the index over-reading a noise-sensitive tendon-insertion difference); they are now a single 10 mm,
floor-anchored. (3) **Dedicated per-cup walls.** The four-finger cluster shared guide flanks at the
inter-finger midline; because the per-finger roll is real anatomy (up to ~27°, measured world-frame ==
body-local so it is anatomy not posture, and dominated by the little finger), a shared wall took one
finger's roll and could float palmar of a neighbour's base plate (the 'side plate under the base'
report). Each cup now carries its own two walls, beside its own finger, each meeting its own floor.
The per-finger roll is kept; only the structure is made self-contained. **`VISION.md` is unchanged** —
its 27th-anchor proof (Bitcoin block 958567) stands; only `MANIFEST.sha256` is re-stamped (**111 files**).

| file | sha256 |
|---|---|
| `VISION.md` (the disclosure) — *unchanged; stands from the 27th anchor, Bitcoin block 958567* | `9b10e86724f558c8783ec708235636fc4c2faba93974ecd31987884fa1bfa266` |
| `MANIFEST.sha256` (hashes of all 111 source + doc files) | `91de9e113857ca8a83fbb505ceccbbe1b355e973d1b5bb4eccec94204b95a285` |

Stamped: **2026-07-21T16:09:37Z** (UTC, submission time). Proof: `MANIFEST.sha256.ots` (the
`VISION.md.ots` proof stands unchanged from the 27th anchor). The outgoing 33rd manifest proof is
archived at `timestamps/MANIFEST.sha256.2026-07-21d.ots` (Bitcoin block 959023).

### Thirty-third — THE CUP WALLS NOW MEET THEIR FLOOR, a FILLET-AWARE ENTRY GATE, and a PRINT-ORIENTATION TOOL

Three things on the road to the first good print, all provoked by looking at the sliced `gauntlet.stl`.
(1) **The cluster's shared side walls were detached from the cup floors.** The four long fingers share
guide flanks that sit at the inter-finger midline, but each cup floor reached only its own finger — so
four of the five walls stood 0.7–1.3 mm off the floor (past the 0.6 mm print fillet), rejoined to the
part only by the thin palmar base-spine tie: floating, floppy guide walls. `manufacture.mount` gains
`FLOOR_REACH`, widening the cluster floors to meet the flanks (a continuous base the walls rise from);
all five now merge, guarded by a regression test in `tests/test_mount.py`. (2) **A fillet-aware entry
gate.** The entry check used the hard union of the mount primitives, but the STL is marched from a
*smooth* min (`BLEND` = 0.6 mm) that inflates junctions outward. `manufacture.entry.smin_sdf` evaluates
that same smooth-min field along each finger's slide-in route, so the fillet — not just the centreline —
must clear; it confirms nothing filleted crosses (nearest strut +6.25 mm off the route, +3.56 mm off the
whole finger; the closest thing is each cup's own +0.43 mm seat). (3) **An optimal print orientation.**
`scripts/orient.py` sweeps build directions over the finished mesh (cups, housing, fillets and all) and
minimises downward-facing overhang area; it agrees with the strut-axis `printability.py` that the part
builds along its long axis, and picks a low-profile orientation (9.8 % overhang vs 15.9 % lying flat,
119 mm tall) written to `out/gauntlet_oriented.stl` for PrusaSlicer's organic supports. **`VISION.md`
is unchanged** — its 27th-anchor proof (Bitcoin block 958567) stands; only `MANIFEST.sha256` is
re-stamped (**111 files**).

| file | sha256 |
|---|---|
| `VISION.md` (the disclosure) — *unchanged; stands from the 27th anchor, Bitcoin block 958567* | `9b10e86724f558c8783ec708235636fc4c2faba93974ecd31987884fa1bfa266` |
| `MANIFEST.sha256` (hashes of all 111 source + doc files) | `6d6aad6f537f9256246e7343077711ba74f29389f5176175270d4a8240e8e3bb` |

Stamped: **2026-07-21T15:03:09Z** (UTC, submission time). Proof: `MANIFEST.sha256.ots` (the
`VISION.md.ots` proof stands unchanged from the 27th anchor). The outgoing 32nd manifest proof is
archived at `timestamps/MANIFEST.sha256.2026-07-21c.ots` (pending Bitcoin confirmation at stamp time;
run `ots upgrade` once the block mines).

### Thirty-second — THE PRINTABLE STL NOW EXPORTS IN MILLIMETRES

A usability fix on the road to the first physical print: `scripts/export_stl.py` builds the mesh in SI
(metres), and slicers assume millimetres, so a raw `gauntlet.stl` imported as a sub-millimetre speck —
a footgun nobody had hit because nothing had been printed yet. The export now scales ×1000 at write
time (after every metre-based clearance check), so `gauntlet.stl` and the `make fit` variants slice at
the right size out of the box (94 × 97 × 158 mm), and the "download and slice" path is finally correct.
**`VISION.md` is unchanged** — its 27th-anchor proof (Bitcoin block 958567) stands; only
`MANIFEST.sha256` is re-stamped (**110 files**).

| file | sha256 |
|---|---|
| `VISION.md` (the disclosure) — *unchanged; stands from the 27th anchor, Bitcoin block 958567* | `9b10e86724f558c8783ec708235636fc4c2faba93974ecd31987884fa1bfa266` |
| `MANIFEST.sha256` (hashes of all 110 source + doc files) | `5bbe4dcef50fbf15345b648208ad47e86dd21ed8b50780dfc1b51ab55a319ac3` |

Stamped: **2026-07-21T13:43:18Z** (UTC, submission time). Proof: `MANIFEST.sha256.ots` (the
`VISION.md.ots` proof stands unchanged from the 27th anchor). The outgoing 31st manifest proof is
archived at `timestamps/MANIFEST.sha256.2026-07-21b.ots` (Bitcoin block 958996).

### Thirty-first — THE FIRST FIRMWARE: a bench field-map sketch for the XIAO nRF52840

The read-out is no longer only a prediction on paper -- there is now firmware to *measure* it.
`firmware/bench_fieldmap/bench_fieldmap.ino` (the repo's first firmware) streams the raw 3-axis field
(Bx, By, Bz) from a TLV493D over USB serial as CSV, so a caliper-stepped magnet logs straight into the
COUPON.md T1/T3 tables. It is built on the Infineon **XENSIV TLx493D** library (which also drives the
device's TLI493D-W2BW), with 8-sample averaging and the I²C bus-lock recovery from
`docs/electronics.md`. **Compile-clean** for `Seeeduino:nrf52:xiaonRF52840` (76.5 KB, 9 % of flash);
not yet hardware-tested. `README.md` gains a "Build" section for the coupon/rig prints and the firmware
toolchain (arduino-cli core/lib install, compile, upload), and the manifest rule now anchors `*.ino`.
**`VISION.md` is unchanged** — its 27th-anchor proof (Bitcoin block 958567) stands; only
`MANIFEST.sha256` is re-stamped (**110 files**).

| file | sha256 |
|---|---|
| `VISION.md` (the disclosure) — *unchanged; stands from the 27th anchor, Bitcoin block 958567* | `9b10e86724f558c8783ec708235636fc4c2faba93974ecd31987884fa1bfa266` |
| `MANIFEST.sha256` (hashes of all 110 source + doc files) | `6f5fb4a144715dbd00163d43f98c122dc373546c77fa6bcee7ccb192d7ca40cb` |

Stamped: **2026-07-21T10:16:45Z** (UTC, submission time). Proof: `MANIFEST.sha256.ots` (the
`VISION.md.ots` proof stands unchanged from the 27th anchor). The outgoing 30th manifest proof is
archived at `timestamps/MANIFEST.sha256.2026-07-21a.ots` (Bitcoin block 958690).

### Thirtieth — THE READ-OUT ELECTRONICS, and the wrist housing that carries them (`docs/electronics.md`)

The electronics design the mechanical/magnetic model implies is now written down. `docs/electronics.md`
captures the read-out chain — five bare **TLV493D** Hall sensors (chip + one cap each; pull-ups per
bus) → a **TCA9548A** I²C mux at the wrist → the **XIAO nRF52840** → BLE HID — and the decisions that
shape it: the **mux-vs-W2BW addressing fork** and its copper trade-off (a mux frees the A1B6's 2-address
limit but breaks the minimal-copper shared bus), the **three-layer lock-up recovery**, and the **34 AWG
enamelled braid** that fits the 1.36 mm groove (with an internal-through-the-hollow-tubes routing idea).
`manufacture/mount.housing` now carries the **mux** beside the XIAO and LiPo (in its dead space) and
carves a **wire-entry slot** for the harness; the LiPo default drops to a **401020** cell (4×10×20 mm),
so the box stands less proud — now **24 × 39.4 × 7 mm**, and the full gauntlet re-exports watertight at
42.0 g. It also states plainly what is still **not built**: firmware, custom PCBs, and the read-out
numbers themselves (pending the stage-1 coupon). **`VISION.md` is unchanged** — its 27th-anchor proof
(Bitcoin block 958567) stands; only `MANIFEST.sha256` is re-stamped (**109 files**).

| file | sha256 |
|---|---|
| `VISION.md` (the disclosure) — *unchanged; stands from the 27th anchor, Bitcoin block 958567* | `9b10e86724f558c8783ec708235636fc4c2faba93974ecd31987884fa1bfa266` |
| `MANIFEST.sha256` (hashes of all 109 source + doc files) | `281d2b19d206d179ac09f67a8527b759861494bb7287022f5cf067f9b514841d` |

Stamped: **2026-07-19T01:33:32Z** (UTC, submission time). Proof: `MANIFEST.sha256.ots` (the
`VISION.md.ots` proof stands unchanged from the 27th anchor). The outgoing 29th manifest proof is
archived at `timestamps/MANIFEST.sha256.2026-07-19a.ots` (Bitcoin block 958631).

### Twenty-ninth — A DOME FLEXURE + a printable bench rig to MEASURE the read-out (`COUPON.md`)

The first bench numbers are in: the flat TPU membrane measured **~230 g at 1.5 mm** against a 20 g
target — too stiff, because a flat clamped membrane *stretches* rather than bends at that deflection.
So this anchor adds the softer flexures and the rig to measure the read-out for real: a shallow **dome**
coupon (`scripts/coupon.py` `dome()` — it rolls/snaps instead of stretching), a printed **field-map
fixture** (`scripts/field_fixture.scad`) that fixes the Hall and slides the magnet over it so T1/T3
need only a caliper + micrometer, and a two-part **silicone dome mold** (`scripts/dome_mold.scad`) to
cast the native keypad-rubber flexure — wall set by the mold gap, not print calibration. The manifest
rule now anchors `*.scad` too (the CAD is the source of record; the coupon/rig STLs are generated).
**`VISION.md` is unchanged** — its 27th-anchor proof (Bitcoin block 958567) stands; only
`MANIFEST.sha256` is re-stamped (**108 files**).

| file | sha256 |
|---|---|
| `VISION.md` (the disclosure) — *unchanged; stands from the 27th anchor, Bitcoin block 958567* | `9b10e86724f558c8783ec708235636fc4c2faba93974ecd31987884fa1bfa266` |
| `MANIFEST.sha256` (hashes of all 108 source + doc files) | `b5d687d66875d8b3482af6124a8bb35cb5e5519d1815e8c4b5eb6cbb21cd48d3` |

Stamped: **2026-07-18T23:38:33Z** (UTC, submission time). Proof: `MANIFEST.sha256.ots` (the
`VISION.md.ots` proof stands unchanged from the 27th anchor). The outgoing 28th manifest proof is
archived at `timestamps/MANIFEST.sha256.2026-07-18c.ots` (Bitcoin block 958601).

### Twenty-eighth — STAGE-1 READ-OUT COUPON PROTOCOL, and a clean TPU test article (`COUPON.md`)

The read-out — that a keypress swings the Hall field ~200× above noise, that the five directions sit
≥ 78° apart, that a neighbour leaks below the noise once baselined — is still a numpy **prediction**
(`manufacture/readout.py`). `COUPON.md` is the first *physical* test: **T1–T7**, each with a
**pre-registered** pass threshold that is the matching `tests/test_readout.py` gate restated as a bench
measurement, so no goalpost can move after a result — and it settles the model's two outright guesses,
`REST_GAP` (3.5 mm) and `CRADLE_LEVER` (0.7). `scripts/coupon.py` generates the TPU article: a rigid rim
clamping a flat membrane of thickness `t`, radius `a` — the clamped diaphragm `flexure.dome` sizes, so
its force/travel is a direct check on **k = 130 N/m** — watertight by construction (a solid of
revolution) and exported in mm, replacing the old non-manifold coupon soup. **`VISION.md` is unchanged**
— its 27th-anchor proof (Bitcoin block 958567) stands; only `MANIFEST.sha256` is re-stamped, now
covering the two new files (**106 files**).

| file | sha256 |
|---|---|
| `VISION.md` (the disclosure) — *unchanged; stands from the 27th anchor, Bitcoin block 958567* | `9b10e86724f558c8783ec708235636fc4c2faba93974ecd31987884fa1bfa266` |
| `MANIFEST.sha256` (hashes of all 106 source + doc files) | `4df2685182e3bc3e2d36b65d7e940d2ecced5946613266b8df2f37edf96bd359` |

Stamped: **2026-07-18T17:41:57Z** (UTC, submission time). Proof: `MANIFEST.sha256.ots` (the
`VISION.md.ots` proof stands unchanged from the 27th anchor).

### Twenty-seventh — THE IMPACT BONE HELD OFF THE FINGERS by a flesh-aware relaxation (§8.15k ggg)

The impact-aware structure looked like its struts passed *through* the fingers. Measured, they did
not — every strut cleared the flesh — but the broad knock-bearing grow hugged it at **~1.1 mm**
against the main design's ~3.4 mm, because the grow's clearance floor is checked at the *nominal* rod
radius while the impact sizer fattens struts to R_MAX and node-relaxation then pulls them toward the
skin. The novelty disclosed here is the fix: those hugging struts **carry the 50 N knock** (it lands at
the buttons, near the fingers), so *deleting* them to win clearance fails SF 2 — **2 mm is the most
removal alone survives**. Instead **move** them: make the form-finding node-relaxation **flesh-aware**
— raise each free node's skin-band floor by its own rod radius (`relax_nodes` takes a per-node `hug`),
so the relaxation pushes the fat struts off the finger at **no knock cost**. Result: **95 % of free
struts clear ≥ 3 mm** (median 5.9 mm) with the knock held at 36 MPa (714 struts, 24.2 g, SF 2); only a
few chord-dip residuals and the intrinsic button/mount struts stay closer. Guarded by
`test_the_impact_bone_keeps_its_free_struts_off_the_flesh`. This anchor also packages the project for
build (`BUILD.md`, `BOM.md`, a one-command `Makefile`, pinned `requirements.txt`, and a per-hand STL
fit) — repo hygiene, not disclosure. (Manifest now **104 files**.)

| file | sha256 |
|---|---|
| `VISION.md` (the disclosure) | `9b10e86724f558c8783ec708235636fc4c2faba93974ecd31987884fa1bfa266` |
| `MANIFEST.sha256` (hashes of all 104 source + doc files) | `e5c4ab5b41b30f1b59744e32678e4429e22ad89aaba2a1fbaa67e0502e1bf0de` |

Stamped: **2026-07-18T14:40:50Z** (UTC, submission time). Proofs: `VISION.md.ots`,
`MANIFEST.sha256.ots`. Confirmed in **Bitcoin block 958567** (`VISION.md`) and **958568**
(`MANIFEST.sha256`).

### Twenty-sixth — THE HARNESS BUS IS NOW EXACT (Dreyfus–Wagner), provably minimal (§8.15l qqq-2)

The 25th anchor meshed the minimal-copper harness with a **metric-MST 2-approximation**; this makes it
**exact**. `mount._steiner_exact` (Dreyfus–Wagner with edge recovery) computes the **true minimum
Steiner tree** over the live struts. On the shipped layout the exact tree is **275 mm** against the
approximation's 283 mm — a **further 2.8 %** — so the 2-power + 2-signal bus is **~1100 mm-equivalent of
conductor, −44 %** against the 490 mm of five independent runs. The router is now **provably optimal**,
not merely near-optimal — the branching Steiner tree still beats the daisy-chain (275 vs 373 mm), so it
is *not* the travelling-salesman problem. The export sinks the wire grooves along the exact tree
(258 mm on the finer print bone); one watertight solid, **40.2 g**, `test_the_harness_bus_is_a_shorter_
shared_tree` and 9 other mount tests pass. Also folds in the `harness.html` gallery view added between
anchors. (Manifest now **99 files** — the view scripts joined it.)

| file | sha256 |
|---|---|
| `VISION.md` (the disclosure) | `026748b264f8fe8f2b4967a9fdeecf617f1500e4827cccd807a44252da39b0e3` |
| `MANIFEST.sha256` (hashes of all 99 source + doc files) | `d93b719af895052f4964fdc3d7b9b00247f6a829d198614816963483e39d6d7c` |

Stamped: **2026-07-18T09:32:41Z** (UTC, submission time). Proofs: `VISION.md.ots`,
`MANIFEST.sha256.ots`.

### Twenty-fifth — THE MINIMAL-COPPER HARNESS BUS, meshed into the export (§8.15l qqq-2)

The 24th anchor *disclosed* the minimal-copper harness (a shared bus, not five point-to-point runs);
this **builds** it. `mount.harness_bus` routes the harness as a **shared Steiner tree over the strut
graph** (a metric-MST approximation) — **one power tree** over all five sensors + the MCU, I²C **signal**
per bus, the conductor count folded in per segment — and `scripts/export_stl.py` now sinks the wire
grooves along that bus: **283 mm in 32 segments** (a uniform 4-wire bundle, the two I²C buses taking
separate routes to the wrist) against the **490 mm** of five independent runs — **−42 % copper**, the
groove widening with the conductor count. One watertight solid, **40.2 g**.
`test_the_harness_bus_is_a_shorter_shared_tree` guards it: shorter than the baseline, every sensor
reaches the wrist, and only live struts carry wire. The **branching** Steiner tree beats the single
**daisy-chain** (283 vs 373 mm), so it is *not* quite the travelling-salesman problem — TSP is the
special case with T-junctions forbidden.

| file | sha256 |
|---|---|
| `VISION.md` (the disclosure) | `1cf7f63cd701db816492fc162ef0506f2c24fd0b153ff6defceb8f443e703904` |
| `MANIFEST.sha256` (hashes of all 98 source + doc files) | `d125a45deb5efc2920fc1673572745cb61a68eb250e1c7ee5e1d84f4f6afcbd1` |

Stamped: **2026-07-17T21:06:58Z** (UTC, submission time). Proofs:
`timestamps/VISION.md.2026-07-17g.ots`, `timestamps/MANIFEST.sha256.2026-07-17g.ots`.

### Twenty-fourth — THE FINGERTIP NOW SEATS IN ITS CUP; a minimal-copper harness BUS (§8.15l ppp-2/qqq-2)

Two things. **(1) The finger was floating above its cup.** The entry check (21st–23rd) had a blind
spot a render caught: `enters_freely` only rejects mount material *inside* the swept finger, so a cup
the finger never reaches passes **vacuously** — and this one did (every fingertip hovered ~7–13 mm
*above* its cup, **0–1 % of the skin inside it**). Cause: the cup was built at `well_frame["pos"] + r`
assuming `pos` is the pulp *centre*, but `pad_pose` returns the pad **surface**. `manufacture/mount.py`
now builds the cup to the **measured** pad and nail (the distal-phalanx skin's floor-direction extent):
floor just palmar of the pad, flanks spanning the finger's real depth, strut to the **palmar sensor
base** (the button node *is* the sensor — a strut to a dorsal edge crossed the finger). The pad now
**contacts** the floor (0.4–0.8 mm), ~50–65 % of the skin cradled; one watertight solid, **40.2 g**.
`test_the_finger_actually_seats_in_its_cup` fails if a fingertip floats again — the regression the
vacuous entry check could not be. **(2) A minimal-copper harness bus (analysed).** The wires need not
run point-to-point: the sensors are I²C, so SDA/SCL are a **bus** and VDD/GND are shared, making the
minimum-copper harness a **shared Steiner tree over the strut graph** — one power tree over all five
sensors + the MCU, signal riding the trunk. Measured on `out/final.npz`: **283 mm** shared vs **490 mm**
of independent paths — a 2-power + 2-signal bus is **−42 %** copper. It is *not* quite TSP: the branching
Steiner tree beats the single daisy-chain (**283 vs 373 mm**); TSP is the branch-forbidden special case.
Disclosed as prior art (§8.15l qqq-2); the Steiner-tree router is not yet meshed into the export.

| file | sha256 |
|---|---|
| `VISION.md` (the disclosure) | `5375c98d984e95e7176ce20b7cbbeefb33005ce46ac2696f99fb696037c11d13` |
| `MANIFEST.sha256` (hashes of all 98 source + doc files) | `e56670478ce176e1135a3844ff2873efef57e96c4397471eed38392446680efa` |

Stamped: **2026-07-17T19:30:57Z** (UTC, submission time). Proofs:
`timestamps/VISION.md.2026-07-17f.ots`, `timestamps/MANIFEST.sha256.2026-07-17f.ots`.

### Twenty-third — THE ENTRY CHECK NOW COVERS THE GAUNTLET STRUTS, HOUSING AND WIRES (§8.15l ppp/qqq)

Two gaps closed. **(1)** The finger-entry check ran only against the mount, not the **gauntlet
struts** — but the truss wraps near the fingertips, so a strut across the slide-in would block just as
a mount wall would. Now checked against the struts too
(`test_the_finger_enters_past_the_gauntlet_struts_too`): the nearest strut sits **+3.2 mm** off the
entry sweep, so the mount's guide flanks stay the binding constraint — *verified, not assumed*. And
`out/entry.html` now renders the **whole gauntlet** (struts + mounts + housing) so the path is shown
against what could block it, not the mount in isolation. **(2)** The **wrist MCU housing + wire
routing**, dropped in the entry-first rebuild, are meshed back in (`mount.housing`,
`mount.harness_routes`): the housing sits **proud of the wrist** (clears 1.7 mm, necked to live-strut
nodes), the wires in **dorsal grooves** (264 segments) — both far from the fingertips, neither touches
the entry route. One watertight solid, **41.1 g**. 131 tests pass.

| file | sha256 |
|---|---|
| `VISION.md` (the disclosure) | `cfd4640fa6d4c8eecf35802cd7830df973e9463cb5ce61209b27df0986e32fe3` |
| `MANIFEST.sha256` (hashes of all 98 source + doc files) | `d87fd04bf8c640620421350f69a1cc2c1b953dc66eb0d09169ae857b7013c459` |

Stamped: **2026-07-17T09:43:25Z** (UTC, submission time). Proofs:
`timestamps/VISION.md.2026-07-17e.ots`, `timestamps/MANIFEST.sha256.2026-07-17e.ots`.

⚠ `TIMESTAMP.md` is deliberately **not** in the manifest. It is written *after* the stamp — it holds
the stamp's own hashes and time — so including it would guarantee `sha256sum -c` failed forever.

### Twenty-second — THE DROP-IN CRADLE PASSES THE ENTRY CHECK TOO (§8.15l ppp)

The 21st anchor rebuilt the sensor FRAME entry-first. This adds the **drop-in TPU cradle**
(`mount.well_insert`) — the cup the finger actually presses, carrying the magnet on the §8.15g dome —
and puts it through the *same* `manufacture.entry` check: the finger enters the cradle's cup (open
proximally, flanks beside, floor below, nail hood and all) **freely**, both individually (≥ 1.6 mm) and
**assembled with the frame** (`test_mount.py`). One watertight TPU piece per finger. `out/entry.html`
now shows the nested cradles the slide-in channels pass through. The read-out physics (mmm–ooo) and the
frame (21st) are unchanged.

| file | sha256 |
|---|---|
| `VISION.md` (the disclosure) | `0b9de23253f1d4427a9efe1d4574e63ae28ae4b0b83f78358fcbfa9504f15a5d` |
| `MANIFEST.sha256` (hashes of all 98 source + doc files) | `d947d09cd78d3571e925f2b903e86503cdbc38c66d5d820c2e873594c2b6654b` |

Stamped: **2026-07-17T08:39:04Z** (UTC, submission time). Proofs:
`timestamps/VISION.md.2026-07-17d.ots`, `timestamps/MANIFEST.sha256.2026-07-17d.ots`.

### Twenty-first — THE FINGER-ENTRY ROUTE, and the mount rebuilt to it (§8.15l ppp)

A correction to this session's own work. The sensor mount (17th–20th anchors) was built checking only
the finger's **static seated** clearance and kept blocking the **route the finger enters by** — the
fingertip slides into the cup along the phalanx axis from the proximal-open end, and a strut across
that path or a rim over the cup leaves it nowhere to come in from. A mount can clear a *seated* finger
and still be un-enterable. That geometry is **withdrawn**. The missing step is now a first-class model:
`manufacture/entry.py` sweeps the distal-phalanx skin along the slide-in and tests it against the
mount's exact primitive SDF, distinguishing a **block** (material *inside* the entering finger) from a
**guide** (a flank *beside* it). `manufacture/mount.py` is rebuilt to pass it — cup open proximally,
sensor palmar below the finger, strut on the dorsal-lateral edge, the four long fingers on a shared
cluster — every finger **enters freely** (≥ 3.1 mm; `tests/test_entry.py`, `test_mount.py`), one
watertight solid, **36.0 g**. The read-out physics (mmm–ooo) is unchanged. `out/entry.html` shows each
finger's slide-in channel passing clear of the mount. The 17th–20th anchors stand as dated floors on
the read-out disclosure; the mount *geometry* they carried is superseded here.

| file | sha256 |
|---|---|
| `VISION.md` (the disclosure) | `e048ee3b4d322891a12d6dfd8b1e8e23f6cea85dd093c1999eff0983c05104d3` |
| `MANIFEST.sha256` (hashes of all 98 source + doc files) | `04838528e43a3ddab737ac2c539e2f54d698deede6183f5a96e85dc710a5c5a6` |

Stamped: **2026-07-17T07:38:49Z** (UTC, submission time). Proofs:
`timestamps/VISION.md.2026-07-17c.ots`, `timestamps/MANIFEST.sha256.2026-07-17c.ots`.

### Twentieth — THE FOUR LONG FINGERS SHARE A CLUSTER, with open finger paths (§8.15l sss)

The 19th anchor flagged that four independent sensor modules are wider than the finger pitch and
interpenetrate at every adjacent pair — needing a shared cluster. **Built** (`wellmod.cluster_frame`).
The long fingers share **one carrier** with **shared inter-finger walls** (the wall between two fingers is
one wall, not two), a palmar base spine linking the Hall seats, and a dorsal rim rail + the struts running
along the wall tops **BETWEEN the fingers, never over a cup** — so every finger drops into its cup and
reaches its sensor freely (entries clear **≥ 3.3 mm**). ⚠ A first cut ran the rim over the finger centres
and choked every entry to 0.1 mm — caught **by eye in the render**, now guarded by
`test_the_cluster_leaves_the_finger_entry_open`. It meshes to **one watertight, non-self-colliding
piece**, each cup walled off, and is **lighter** than the four modules were (whole part **42.2 g**, down
from 49.9). The thumb keeps an independent module. The packing `xfail` is retired; **130 tests pass**. ⚠
Open: the drop-in inserts are still per-finger and overlap the shared walls at the tightest pair — they
need matching narrower/webbed cups.

| file | sha256 |
|---|---|
| `VISION.md` (the disclosure) | `96505cbf5bf642442b2ae5701e6a80bb66b83072bffc33dac84ae56671ab4609` |
| `MANIFEST.sha256` (hashes of all 98 source + doc files) | `eba779014fba7bc89817dd6435b67f883048ffb1b9c563537d74298ce2ec8eb1` |

Stamped: **2026-07-17T06:52:11Z** (UTC, submission time). Proofs:
`timestamps/VISION.md.2026-07-17b.ots`, `timestamps/MANIFEST.sha256.2026-07-17b.ots`.

### Nineteenth — THE STRUT TIES IN DORSALLY, and the collar nests the insert (§8.15l rrr/sss)

Two module bugs the one-sensor render exposed. **(1)** The truss tied into the frame **down by the palmar
magnet** — the wrong side; it now lands on a **dorsal-lateral rim + distal brace** (the nail side,
**opposite the magnet**, measured **3.8 mm** clear of the finger). **(2)** The frame collar was **inboard
of the insert cup** (±7.9 vs ±9.5 mm), so the two parts could not nest; the collar now sits **outboard**
and the insert drops in between the walls. Still one watertight solid (component count 1), but **49.9 g** —
proper nesting is heavier. Sizing the collar to nest widened every module past the finger pitch, so **all
three adjacent long-finger pairs** now interpenetrate (index-middle, middle-ring, ring-little), not just
middle-ring: the four long fingers need a **shared cluster**, the next real piece of work
(`test_adjacent_long_fingers_need_cluster_packing`, an `xfail`). A new `scripts/sensor_view.py` renders one
module cut away beside the field-vs-motion signal — which is what caught all of this.

| file | sha256 |
|---|---|
| `VISION.md` (the disclosure) | `dbefe524ccec8f018bb48b96861a1250ef3ceeedc37b1d5a67424cdaa9c20ffd` |
| `MANIFEST.sha256` (hashes of all 98 source + doc files) | `1915ea9d2a35fcbc56f10b14e9ba84b921f4cfce69dcad22c33080e4ef03af78` |

Stamped: **2026-07-17T05:52:34Z** (UTC, submission time). Proofs:
`timestamps/VISION.md.2026-07-17a.ots`, `timestamps/MANIFEST.sha256.2026-07-17a.ots`.

### Eighteenth — CORRECTION: the sensor part was 31 pieces, not one solid; now tied into one (§8.15l rrr)

The 17th anchor claimed the sensor gauntlet meshed as "one watertight solid." It was watertight but in
**31 disconnected pieces**: the five modules and the MCU housing floated **~10 mm off the skeleton**,
because `well_frame`'s fingertip pad is **not** the structure's button node (`ground()` places them
differently), and the housing neck anchored at the anchor *centroid* — empty space. The watertight check
passed; only counting **components** caught it. Fixed: each frame is tied to its button node with
**stalks**, the housing to its nearest **live-strut nodes**, and the sub-mm³ marching-cubes debris is
dropped — now **one connected body, component count 1**, **42.1 g** (the 39.0 g figure was measured off the
broken mesh). The MCU box is also re-oriented along the local skin normal so it sits **proud of the wrist**
instead of cutting in. A new `scripts/gauntlet_solid_view.py` renders the STL back with the magnets and Hall
sensors flagged in contrasting colour, so the mounts are visible.

| file | sha256 |
|---|---|
| `VISION.md` (the disclosure) | `ad483d8c11148d49c234160da6d5fe21ce83a0be9dd19a0bddfb8c887c06a81a` |
| `MANIFEST.sha256` (hashes of all 97 source + doc files) | `d4861889384256b712e9391b64011cd3eb35c02dc1fb5cdb0ab65e1fef1b3533` |

Stamped: **2026-07-16T22:53:48Z** (UTC, submission time). Proofs:
`timestamps/VISION.md.2026-07-16h.ots`, `timestamps/MANIFEST.sha256.2026-07-16h.ots`.

### Seventeenth — THE READ-OUT: the field a moving magnet presents to the Hall, and the printed module (§8.15l)

§8.15g sized the finger-well's restoring spring (a TPU dome) but **deferred the signal** — the field a
moving magnet presents to the Hall. This closes it. A **Ø3×1 mm N42** disc on the cradle over a **3-axis
Hall** reads a keypress at **~430 LSB — ~200× the sensor noise** (`manufacture/readout.py`, an analytic
exact-cylinder + point-dipole model, no new dependency); the five joystick directions sit **≥78° apart**
(0 nearest-template errors in 10⁵ draws at the datasheet noise), and the tightest well pair's crosstalk is
**below the noise floor**, baselined out. The wells become a printable **two-part module**
(`manufacture/wellmod.py`; a `carve()` SDF-subtraction added to `manufacture/mesh.py`): a rigid PA frame
with the Hall seat and re-entrant wire grooves carved in, and a **drop-in keyed TPU cradle** holding a
press-fit magnet over the §8.15g dome. The whole gauntlet — five modules, the harness grooves, a wrist
nRF52840 housing — meshes **one watertight, winding-consistent solid** (39.0 g; **+13.5 g** measured for the
sensors). ⚠ Stated, not hidden: the tightest module pair (**middle–ring**) interpenetrates and needs
cluster-level packing; the read-out is a **model** the stage-1 coupon bench must confirm; the firmware is
**outlined, not built**. 128 tests pass, 1 xfail marking that packing gap.

| file | sha256 |
|---|---|
| `VISION.md` (the disclosure) | `b7d68754afc631c980f8aa8b9c30d268dc33a5a3c06428ac3ff532f427b9029a` |
| `MANIFEST.sha256` (hashes of all 96 source + doc files) | `ae16c7936218aa19408d1b14fc8b460fd462edd7d3359dbba1bae0d57b2f3a0d` |

Stamped: **2026-07-16T22:09:56Z** (UTC, submission time). Proofs:
`timestamps/VISION.md.2026-07-16g.ots`, `timestamps/MANIFEST.sha256.2026-07-16g.ots`.

### Sixteenth — RANK BY STRAIN ENERGY FOR FREE, off the OC's own solve (§8.15k, claim fff)

The prune fix (14th anchor) ranked deletions by strain energy via a second FEM solve, and estimated that
at "~2× the prune time." **Both the mechanism and the estimate are now improved.** `size` reads the strain
energy off the OC's *own* solve — the sizer already computes the displacements and the radius-scaled element
stiffnesses, so the per-member energy density (½·uᵀk u / L) falls out with **no second solve**. And the
"~2×" was pessimistic: **measured, the extra solve was ~20%** (a prune goes **38 → 30 s**), because a prune
step is dominated by the OC's own sizing solves, not the one ranking solve. The truss lands unchanged (253 →
250 members); 110 tests pass.

| file | sha256 |
|---|---|
| `VISION.md` (the disclosure) | `21f5f3ef458a226fb30e2518418873cfc32ec2079fb072f1a62bd6ebe1952829` |
| `MANIFEST.sha256` (hashes of all 90 source + doc files) | `8abf4d692e7278199bc423cf3926f2515e13c047ee7217e986567c53ee9d39bd` |

Stamped: **2026-07-16T17:09:24Z** (UTC, submission time). Proofs:
`timestamps/VISION.md.2026-07-16f.ots`, `timestamps/MANIFEST.sha256.2026-07-16f.ots`.

### Fifteenth — RE-CHARACTERISE THE FRIENDLY COMPARISON UNDER THE FIXED PRUNE (§8.15v)

With the prune fixed (fff), the ergonomic-floor study splits into two regimes, and the split is the finding.
The **device** (grow-based bone) stays **touch-limited — all 408 members sit on the 1.5 mm floor** (was
95%), sized by the hand: solid 20.9 g → **hollow 12.7 g (−39%)**, over-stiff at 172 µm, so the marrow comes
out free. But touch-limited is a property of **density**, not the floor: ask the fixed prune to minimise
mass and it carves a **sparse truss — 61 members, every one at the r_max ceiling (2.5 mm), load-limited,
17.4 g** — which **cannot be hollowed** (at r_max *for stiffness*; removing the core drops the second moment
to ~79% and the well deflection past the 500 µm gate). So touch-limited-dense-and-hollow (**12.7 g**) beats
load-limited-sparse (**17.4 g**): the ergonomic floor plus the marrow cavity is **vindicated by the fix, not
overturned**. README's touch-limited line (now 100%), hollow line (−39%), and trabecular line (400 → 61)
updated to match.

| file | sha256 |
|---|---|
| `VISION.md` (as of 2026-07-16, 16:43Z) | `6019ba7ea36dd5f3055778e810b98ab90c7d2d34abe7fafda8ad22e062b9bfab` |
| `MANIFEST.sha256` (90 files) | `b58cb9305b4fcced0d06a3014e4518de209ed7cd4bbef78f93ffd482bee9ae0d` |

Stamped: **2026-07-16T16:43:22Z** (UTC, submission time). Proofs:
`timestamps/VISION.md.2026-07-16e.ots`, `timestamps/MANIFEST.sha256.2026-07-16e.ots`.

### Fourteenth — FIX THE PRUNE'S MEMBRANE TRAP: rank deletions by strain energy (§8.15k, claim fff)

The membrane was a one-line **ranking** bug. `grow` and `size_and_prune` are both top-down ESO; the only
difference that mattered is the signal each deletes by. `grow` ranks by **strain energy** at a fixed
radius, where an idle member reads as idle whatever the sizer later does; `size_and_prune` ranked by the
**OC-sized radius**, which the OC returns *uniform* on a membrane — no signal, so it deleted ~blindly and
stalled. Measured on the same 8 mm lattice: `grow` carves a **205-strut / 7.2 g** truss (with node
relaxation on *or* off — so it was never relaxation or pitch, only the ranking); the old prune stalled at
**1149 / 41 g**. So `size_and_prune` now ranks deletions by strain energy too, and it carves **253 members
/ 8.9 g** — grow's 205 plus the ~50 FDM support struts the print version keeps. The impact and bone
numbers are unchanged (both were already grow-based); the fix corrects the `printable`/`ergonomic`/
impact-bolt-on prunes. Guarded by `test_the_prune_carves_a_truss_not_a_membrane`, which fails if the prune
ever weighs more than 2.5× the grow again. It costs one extra FEM solve per prune step (~2× the prune
time); reading the strain energy off the OC's own solve would make it free — a noted follow-up.

| file | sha256 |
|---|---|
| `VISION.md` (as of 2026-07-16, 14:42Z) | `865a5bc43b4751b63f37058f401081e50540ebf6a9db4996dc58d5c405b2b310` |
| `MANIFEST.sha256` (90 files) | `fb13ad82e5f81b40e33b72a8f8e6c8e1f1458134251d55cd2765480b0145f8b4` |

Stamped: **2026-07-16T14:42:32Z** (UTC, submission time). Proofs:
`timestamps/VISION.md.2026-07-16d.ots`, `timestamps/MANIFEST.sha256.2026-07-16d.ots`.

### Thirteenth — CORRECTION: the prune's membrane is not enslavement-specific (§8.15k, claim fff)

The twelfth anchor's (fff) said the *pre-enslavement* design "pruned cleanly to 138 members / 8.5 g" and
only the enslavement design "trapped" — and it read the plateau as the build-support rule. **Both were
published without measuring, and both are wrong.** The old design was gitignored and overwritten, so the
138 came from stale doc numbers, not a run. Measured against the archived pre-enslavement front
(`out_archive/pareto_seed1.pkl`), its knee **also prunes to a uniform membrane (754 members, 27.8 g)**, as
does the current design *unconstrained* — no nozzle floor, no support protection (**1799 members,
62.5 g**). The 138 / 8.5 g truss is from an **older design era** and is not reproducible on any recent
design. The real cause: for the recent design family the buttons sit **62–71 mm from the anchors**, so
keypress load fans out across the dorsal skin and every member carries an equal share — a **membrane**.
Uniform strain energy means the sizer parks every radius at 0.90 mm (**p90/p10 = 1.00**) and greedy
top-down deletion has no signal, so the prune dead-ends in a heavy uniform net: a **local optimum** the
grow (bottom-up, free nodes) sidesteps. Enslavement only made it **1.5× heavier** (754 → 1154) by
extending the fingers ~20 mm farther from the anchors. Render-from-grow stands; the reasoning is now
measured, not inferred.

| file | sha256 |
|---|---|
| `VISION.md` (as of 2026-07-16, 12:13Z) | `d7554838166f05418bfdce07440e704c6e520c22d213d5e3bdd670a18ccd6114` |
| `MANIFEST.sha256` (90 files) | `40a7633e049358ff9ef1de1edad39a9eca7c585406b47337dd1832afd0ee5c8e` |

Stamped: **2026-07-16T12:13:49Z** (UTC, submission time). Proofs:
`timestamps/VISION.md.2026-07-16c.ots`, `timestamps/MANIFEST.sha256.2026-07-16c.ots`.

### Twelfth — RENDER THE BONE FROM THE GROW, not a print-time re-prune (§8.15k, claim fff)

⚠ **Corrected by the current anchor above:** the plateau is a membrane *local optimum*, not the
build-support rule, and it is **not** enslavement-specific (the pre-enslavement design membranes too). The
"138-member" comparison below was unmeasured and is false. The render-from-grow fix itself stands.

Regenerating the gauntlet for the enslavement design exposed a **print-pipeline trap**. The keypress
bone had been re-derived for printing by an independent 8 mm re-prune (`size_and_prune`); on this design
its build-support rule (never delete a node's last down-strut) plateaued it at a **dense 1149-member
skin, 33.9 g hollow** — support-limited, not stiffness-limited (the worst well sat at 338 µm, well inside
the 500 µm gate). The **impact** structure settles it: it carries the keypress *and* the 50 N knock at
**23.2 g**, so a keypress-only bone cannot honestly need 33.9 g. So `bone.py` now renders the **grown**
topology directly — the one the objective already form-found off the grid — only **sizing** it to the
ergonomic floor: **7.54 g** beam / **12.7 g** hollow, 410 members, within 6% of the old committed 12.0 g.
Impact re-optimised to **23.2 g** (was 24.2 g), 39% lighter than the 37.7 g bolt-on. Grow it, don't
re-prune it.

| file | sha256 |
|---|---|
| `VISION.md` (as of 2026-07-16, 09:40Z) | `40cc56d91cf9b307e0e283d3aecfbf85fb235ed3c78261985c459e543a619d26` |
| `MANIFEST.sha256` (90 files) | `6bfc868638a875a8361b238d305413de283a097c9eca6a7e4a6ecced8e269c5c` |

Stamped: **2026-07-16T09:40:08Z** (UTC, submission time). Proofs:
`timestamps/VISION.md.2026-07-16b.ots`, `timestamps/MANIFEST.sha256.2026-07-16b.ots`.

### Eleventh — ENSLAVEMENT, grounded per finger, and the layout re-optimised under it (§6)

The winning layout had posed the **ring extended while its neighbours flexed** — raised 9 mm, and the
design leaned on it (+33% effort and key-overlap when clamped). No hand holds that: MyoHand models the
four long-finger flexors as independent actuators, but they share a belly (the OpenSim hand models
drive the FDP's four slips from one activation). We express that coupling **kinematically, per finger**,
by the **individuation index** — `INDIVIDUATION` (Häger-Ross & Schieber 2000, `Source.LITERATURE`):
the ring may deviate ±0.035 from the common curl where the index may ±0.075, replacing the single
symmetric `COMMON_DRIVE` guess. Re-optimised under it, the ring sits **+2.1 mm** (was +8.9), feasible,
effort and mass comparable — the illusory raise cost nothing to remove.

| file | sha256 |
|---|---|
| `VISION.md` (as of 2026-07-16, 07:25Z) | `1b841e6478146f91f529ceb65a6e73bac48706263ee44d9ec1731e8e53add1da` |
| `MANIFEST.sha256` (90 files) | `81c526a05c0c3d4b3d2009ae83dabb84852b7726d1366652215957c539117827` |

Stamped: **2026-07-16T07:25:50Z** (UTC, submission time). Proofs:
`timestamps/VISION.md.2026-07-16a.ots`, `timestamps/MANIFEST.sha256.2026-07-16a.ots`.

### Tenth — SHELL vs LATTICE: the sandwich weighed by a coupled plate FEA (§8.15k, claim eee)

The render looks like a shell, so an explicit one was weighed end to end. A shell for a knock on the
back is pointless (that knock sizes 0.1 g); the discrete tissue anchors ARE a bottleneck, and a
**coupled lattice + finite-stiffness plate FEA** cuts the worst well-knock stress **96 → 52 MPa** — but
that thins the lattice only ~3–4 g while the shell costs ≥ 5 g, so **no shell beats the pure lattice**
(sandwich ≥ 27 g vs **24.2 g**). The density is fundamental; the shell's value is continuous skin
bearing (comfort), already met by the strap (§8.15j). Recorded with its reversals, the FEA the arbiter.

| file | sha256 |
|---|---|
| `VISION.md` (as of 2026-07-15, 21:46Z) | `f1b19f6a015751771b2d67a827937a82d672ef8018d4b4de41c99b037b7afa9a` |
| `MANIFEST.sha256` (90 files) | `ebad7d7b37c804727bc7e645c997d9514a30dfa0712f430a48d9a894f439d891` |

Stamped: **2026-07-15T21:46:13Z** (UTC, submission time). Proofs:
`timestamps/VISION.md.2026-07-15g.ots`, `timestamps/MANIFEST.sha256.2026-07-15g.ots`.

### Ninth — FORM-FINDING BELONGS IN THE WHOLE PIPELINE (§8.15k, generalised)

The shape-convergence pass generalised, and a correction. The **decoupled** pipelines that make the
definitive structures — size-then-prune-then-curve for the keypress bone, grow-then-co-size for the
impact one — curved their load paths but **never moved the nodes**, leaving them staircased on the
grid. `relax_nodes` (form-finding) belongs in *both*, not only in the render: added to the keypress
bone it drops the flagship **11.05 g → 8.51 g (−23%)**, gate still 499 µm (A/B verified: relaxation
off reproduces 11.05 g exactly). This **corrects** the `relax_nodes` note that the pass is "cosmetic,
not where the grams are" — true only of the grow-front designs it was measured on, which are already
relaxed; on a never-relaxed definitive structure it is worth a fifth of the mass.

| file | sha256 |
|---|---|
| `VISION.md` (as of 2026-07-15, 19:44Z) | `9b106711890b9cb4c91b1b2070a493d9ace1517838a3c20c346573bb5cb6fe58` |
| `MANIFEST.sha256` (86 files) | `6003414c039f78efd4b3cdf86229bceb814f80117e7b44ce6ce1069ea8e320d2` |

Stamped: **2026-07-15T19:44:25Z** (UTC, submission time). Proofs:
`timestamps/VISION.md.2026-07-15f.ots`, `timestamps/MANIFEST.sha256.2026-07-15f.ots`.

### Eighth — the IMPACT STRUCTURE, SHAPE-CONVERGED (§8.15k, revised)

The impact re-optimisation, taken to convergence in *shape*, not only topology. The co-sized skeleton
came off the lattice **staircased** — ~8% of its nodes turned a load path past 75° — and never got the
**form-finding** pass. Adding `relax_nodes` after the sizing straightens it (**kinks > 75°: 40 → 11**)
and, because a starved dense lattice had members sized thick to resist *bending* at their kinks, lets
them carry *axially* instead: **29.3 g → 24.2 g**, so in-the-loop is **34% lighter** than the bolt-on.

| file | sha256 |
|---|---|
| `VISION.md` (as of 2026-07-15, 19:23Z) | `4f47c62663c1ba702823088afec7c7c8eb2132a387af54e230daa0fa70c58a7a` |
| `MANIFEST.sha256` (86 files) | `5d233591b2dde6ac48746c70fb97b96dac2239a40d4074c3ae6427af0b967d54` |

Stamped: **2026-07-15T19:23:27Z** (UTC, submission time). Proofs:
`timestamps/VISION.md.2026-07-15e.ots`, `timestamps/MANIFEST.sha256.2026-07-15e.ots`.

### Seventh — the KNOCK RE-SIZES THE BONE (§8.15k, as first disclosed)

Impact is the binding structural load, not the keypress. A 50 N knock breaks the deflection-optimised
bone (**348 MPa** against a 70 MPa yield), while fatigue has a 16× margin. And the knock wants a
*different* skeleton — broad and load-sharing, not the sparse keypress one thickened: grown with the
knock in the load set, the two topologies share only **20% of their members** (Jaccard 0.20). Growing
WITH the knock and co-sizing for the gate AND the stress is **19% lighter** than bolting the impact on
afterward (before the shape-convergence pass above took it to 34%).

| file | sha256 |
|---|---|
| `VISION.md` (as of 2026-07-15, 17:57Z) | `037c9c00e9f3bd4f68e1d06ee1fa05405a1fb20e6fafd45f1a98e5fa1872a215` |
| `MANIFEST.sha256` (84 files) | `391d83a5a57ad04690d6f63e44d1c59ab7ca95e8ad9d24b308ae2d0240db1507` |

Stamped: **2026-07-15T17:57:47Z** (UTC, submission time). Proofs:
`timestamps/VISION.md.2026-07-15d.ots`, `timestamps/MANIFEST.sha256.2026-07-15d.ots`.

### Sixth — the GAUNTLET ON THE OUTSIDE OF THE STRAP (§8.15j)

The design decision that the *strap*, not the gauntlet, is what meets the hand: the gauntlet mounts
on the OUTER face of the soft TPU strap, so the strap is the sole hand interface — cushion, tension
tether, and load-spreader in one part, attached by loops printed into the strap itself. Re-solved:
the 500 µm gate holds (**499 µm**, +0%) with the soft strap in the load path, because TPU is stiffer
in through-thickness compression than the tissue it sits on. This **supersedes the inner bearing
shell (§8.15i)** as the skin interface.

| file | sha256 |
|---|---|
| `VISION.md` (as of 2026-07-15, 14:31Z) | `d92e96496c21acec7568bbbfe53db0aa1fbba4c6caac4fa556554b4f41d0a7b5` |
| `MANIFEST.sha256` (80 files) | `4775e3d98f00977352b0d077cd85b0d867876eff7e164f1db57c29ee071cc0de` |

Stamped: **2026-07-15T14:31:37Z** (UTC, submission time). Proofs:
`timestamps/VISION.md.2026-07-15c.ots`, `timestamps/MANIFEST.sha256.2026-07-15c.ots`.

### Fifth — the SANDWICH GATE RE-SOLVE (§8.15i)

The sandwich inner face added to the per-element solver, and the 500 µm key-deflection gate re-solved
at the bone's real sections: the buttons hold at **485 µm**, so the face does not compromise
key-crispness (its value is the IMPACT, not the gate).

| file | sha256 |
|---|---|
| `VISION.md` (as of 2026-07-15, 13:43Z) | `772124bf2730861e27aa572b66adb057230a8b4362403353904642b1b2bfec0d` |
| `MANIFEST.sha256` (77 files) | `ce4971b13227485c8944c995465a29696cf6361222e5af854892c1a29197bdd2` |

Stamped: **2026-07-15T13:43:52Z** (UTC). Proofs: `timestamps/VISION.md.2026-07-15b.ots`,
`timestamps/MANIFEST.sha256.2026-07-15b.ots`.

### Fourth — the SENSOR, the STRAP ANCHOR, and the BEARING SHELL (§8.15g–i)

Adds the wearable's two practical subsystems and its skin interface: the **contactless-Hall finger
well** — a magnet on a printed **TPU dome** over a 3-axis Hall — with the flexure material chosen by
**σ_fatigue/E** (the maximum recoverable bending strain) and the plunge that must *bend*, not
compress; the measured result that **every well is five-way** (the ulnar "three-way" limit was a
cradle artefact — the interossei are adequate, and the extensor hood a genuine but *non-operative*
MyoHand gap); the **strap anchor** — the band routed as the convex hull of (skin ∪ device) so it
rides *over* the structure it holds down, a **watch-lug** capturing a pin in shear, one adjustable
strap fitting the 5th–95th percentile hand; and the **inner bearing shell** as an **impact
distributor** — a plate on the soft-tissue elastic foundation, sized by the *knock* not the preload —
built as a **sandwich** with the topology-optimised lattice as its core.

| file | sha256 |
|---|---|
| `VISION.md` (as of 2026-07-15, 09:32Z) | `4d663f98528165d61fa3abbe4327db7dc7e64fb934ba447619bb626d85a6b9ad` |
| `MANIFEST.sha256` (75 files) | `3ebcb9b285d300494a746acddc0d23f233083ec204a69b7e2be079b5222d0138` |

Stamped: **2026-07-15T09:32:00Z** (UTC). Proofs: `timestamps/VISION.md.2026-07-15a.ots`,
`timestamps/MANIFEST.sha256.2026-07-15a.ots`.

### Third — HUMAN FACTORS as the organising principle (§5g), and the whole structural stack

Adds: **human factors as the organising principle** (§5g) — nearly every constraint here is a fact
about PEOPLE, only three are facts about a machine, and reproducibility ("one person, one printer")
is a HUMANIST constraint; the **ergonomic floor** `SKIN_R` and the finding that it, not the nozzle,
is what makes a topology-optimised structure **trabecular**; **curved (spline) load paths**;
**oriented elliptical and stadium sections** and the proof that a circle is the worst section for a
member that bends; and the central measured result — **the device is TOUCH-limited, not
load-limited** (95% of its members are as thick as they are because a HAND must bear them), so **the
bone is HOLLOW**.

| file | sha256 |
|---|---|
| `VISION.md` (as of 2026-07-14, 21:40Z) | `15d99f392e9fe34fdec8908cb602bd49e32349c0667c398d005790318296866b` |
| `MANIFEST.sha256` (63 files) | `f0e4fb4db6eb348e8e760464a40b1d58e5eefab1abe560ad1b2a0a3388335d91` |

Stamped: **2026-07-14T21:40:41Z** (UTC). Proofs: `timestamps/VISION.md.2026-07-14b.ots`,
`timestamps/MANIFEST.sha256.2026-07-14b.ots`.

### Second — the dorsal gauntlet, the structure, the anchor, the manufacture (§8.8–8.14)

| file | sha256 |
|---|---|
| `VISION.md` (as of 2026-07-14, 15:24Z) | `a327fa03b832e334dff709dabfccf7fb8dc01ca760da70f380d64b1930cebb14` |
| `MANIFEST.sha256` (53 files) | `e16f938ae7641e1758f625408e21ca4b6269a8b2893b2205da22a168bf0ebf4b` |

Stamped: **2026-07-14T15:24:50Z**. Proofs: `timestamps/VISION.md.2026-07-14a.ots`,
`timestamps/MANIFEST.sha256.2026-07-14a.ots`.

### Original — the palmar body and the layout method (§8.1–8.7)

| file | sha256 |
|---|---|
| `VISION.md` (as of 2026-07-12) | `a1d7c32e743780be7fee98dccf2ef727d4ea26fda8d2b970862b7357f91232be` |
| `MANIFEST.sha256` (27 files) | `4c45f8cdd21e1f5b48e0ad9852ad195cf5c4a07d89d1b46ba3262ef52367c1e4` |

Stamped: **2026-07-12T22:50:22Z**. Proofs: `timestamps/VISION.md.2026-07-12.ots`,
`timestamps/MANIFEST.sha256.2026-07-12.ots`.

⚠ The original proofs cover the *original* file contents. To verify them you need that version of
`VISION.md` — `git show <commit>:VISION.md`. This is why the manifest is hashed separately: the
manifest pins the whole tree at that instant.

## How the proof works

[OpenTimestamps](https://opentimestamps.org/) aggregates the hash into a Merkle tree and
commits the root into the **Bitcoin blockchain**. Once a block confirms it, the proof shows
the file existed *before that block was mined* — a fact anchored in the most expensive
public ledger in existence, verifiable by anyone, forever, with no trusted third party.

The attestation matures in a few hours (it needs a Bitcoin block). Until then `ots verify`
reports a *pending* attestation from the calendar servers; afterwards it reports a
**Bitcoin block height and time**.

## Verify it yourself

```bash
pip install opentimestamps-client

ots verify VISION.md.ots          # -> "Success! Bitcoin block <N> attests existence as of <date>"
ots verify MANIFEST.sha256.ots

# and check the manifest still matches the tree it covers
sha256sum -c MANIFEST.sha256
```

If `ots verify` reports "pending", upgrade the proof once the block is mined:

```bash
ots upgrade VISION.md.ots MANIFEST.sha256.ots
```

## Belt and braces

The Bitcoin anchor is the strong one, but redundancy is cheap:

- **Zenodo DOI** — archival, independently timestamped, and the venue patent examiners and
  courts actually accept. See `CITATION.cff`.
- **Internet Archive** — snapshot the public repository URL.
- **IP.com / Linux Defenders** — purpose-built defensive-publication venues that examiners
  search.

⚠ Not legal advice.

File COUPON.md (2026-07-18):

# Stage-1 coupon — read-out bench test protocol

> **Why this exists.** Everything about the ExoKey key — that a fingertip press swings the Hall
> field ~200× above its noise, that the five directions are tellable apart, that a neighbour well
> does not false-trigger, that the TPU dome gives a ~20 gf key and survives — is a **prediction from
> a numpy model** (`manufacture/readout.py`, `manufacture/flexure.py`). Nothing has been built. This
> is the first physical test, and it decides whether the read-out is real. Two of the model's inputs
> are outright **guesses** it exists to settle: `REST_GAP` (3.5 mm) and `CRADLE_LEVER` (0.7).
>
> **Pre-registration.** The pass thresholds below are **fixed before any coupon is printed or
> measured**, and they are the model's own design gates (`tests/test_readout.py`) restated as bench
> measurements. Record the date you freeze them; do not edit a threshold after seeing a result. A
> result that misses its threshold is a finding, not a failure to be tuned away — that is the whole
> point of measuring.

Registered: __________ (fill in before the first measurement). Model revision: `git rev-parse HEAD`.

---

## What the model predicts (the numbers under test)

Magnet **Ø3 × 1 mm N42** (Br 1.29 T) · Hall **TLI493D-W2BW class** (0.098 mT/LSB, ±130 mT, ~0.2 mT
RMS noise) · rest gap **3.5 mm** · key travel **1.5 mm** · target spring **130.7 N/m** (196 mN / 1.5 mm).

| quantity | predicted | source |
|---|---|---|
| magnet dipole moment | 7.26 × 10⁻³ A·m² | `readout.moment` |
| rest field (gap 3.5 mm) | ≈ 19 mT | `readout.cyl_axial_B` |
| full-plunge field (gap 2.0 mm) | ≈ 61 mT | `readout.cyl_axial_B` |
| plunge swing ΔBz (rest→full) | **41.9 mT = 427 LSB = 209× noise** | `readout.delta_B('click')` |
| hard-stop field (gap 1.7 mm) | 80 mT = 62 % of range | `readout.cyl_axial_B` |
| lateral tilt signal (each of 4) | 7.1 mT = 36× noise (6.3 mT transverse + −3.3 mT plunge) | `readout.delta_B` |
| min pairwise angle, 5 directions | **78°** | `readout.discriminability` |
| classifier error (10⁵ noisy draws) | **0** | `readout.classify_mc` |
| neighbour crosstalk @ 18.6 mm | static 0.23 mT, modulation 0.055 mT | `readout.crosstalk` |
| scan power / life | 1.48 mA → 68 h on 100 mAh | `readout.scan_power` |
| TPU dome thickness for k=130 N/m | 0.322 mm (a=6 mm), 0.356 mm (a=7 mm) | `flexure.dome` |

---

## Coupons and rig

**Print (TPU membrane sweep — the printability question is real: 0.32 mm is at the FDM single-
perimeter floor):**
- Generate: `PYTHONPATH=. .venv/bin/python scripts/coupon.py` → six watertight
  `out/coupon_t{0.25,0.32,0.40}_a{6,7}.stl` (a rigid rim clamping a flat membrane of thickness `t`,
  radius `a`, with a central boss for the Ø3×1 mm magnet). This is exactly the clamped diaphragm
  `flexure.dome` sizes, so its force/travel is a direct check on k. Exported in **mm**.
- **Design point: `coupon_t0.32_a6.stl`.** Print the whole `t` sweep to find which thickness lays down
  without gaps on your nozzle (a 0.25 mm nozzle helps the thin ones).
- A rigid **seat/spacer** (any PA/PETG part, or an improvised feeler-gauge stack) holds the Hall under
  the coupon at the design 3.5 mm rest gap for T1/T3.
- **Softer flexures, because the flat membrane measured ~230 g at 1.5 mm — far too stiff (it stretches,
  not bends).** Two routes: a shallow **dome** (`scripts/coupon.py` also emits
  `out/coupon_dome_a6_t0.32_h{1,2,3}.stl` — it rolls instead of stretching, and can snap); or, softer
  still, **cast silicone** — print the two-part mold `scripts/dome_mold.scad`
  (→ `dome_mold_cavity.stl` + `dome_mold_core.stl`), pour a two-part silicone, press, cure. Silicone is
  the native keypad-dome material (soft, isotropic, near-immortal in fatigue) and the wall is set by the
  mold gap, not by print calibration — check platinum-cure inhibition against your filament first.

**Buy:**
- 5+ **Ø3 × 1 mm N42** discs (e.g. supermagnete S-03-01-N) — some spares; verify grade.
- 2+ **TLV493D / TLI493D-W2BW breakouts** (one under test, one as the neighbour for crosstalk).
- A microcontroller to read the Hall over I²C and log **raw (Bx, By, Bz) in LSB** at ≥ 500 Hz.

**Rig (the measurements need controlled displacement, not a finger):**
- **A printed field-map fixture** (`scripts/field_fixture.scad` → `fixture_hall_base.stl` +
  `fixture_magnet_sled.stl`): fixes the Hall, slides the magnet over it in X with a **caliper** setting
  the position at a set gap. It decouples the SIGNAL (rigid magnet vs Hall) from the flexure, so T1/T3
  need only your caliper + micrometer, not a load cell. Set the pocket to your breakout and verify the
  gap with a feeler gauge.
- A **micrometer / motorised linear stage**, ≤ 0.05 mm resolution, to set the plunge gap and lateral
  offset precisely (the model's x-axis is displacement — the bench must own it).
- A **force gauge / load cell**, mN resolution, for the spring curve.
- A tilt fixture (set 0–8° about the crown) for the lateral-direction signals.
- Optional: a thermal source (ambient → ~35 °C skin) and a cyclic actuator for fatigue.

---

## Tests — each isolates one claim, each has a frozen threshold

Isolate before you compose: **T1** (magnet+sensor, no dome) and **T2** (dome, no magnet) first, then
**T3+** on the full cradle. Every threshold below is the corresponding `tests/test_readout.py` gate.

### T1 — Field vs gap (magnet + Hall only) → confirms `REST_GAP` and the plunge budget
Mount a magnet on the stage over the Hall. Step the gap from ~4 mm down to the 1.7 mm hard stop,
logging Bz at each step. Fit against `cyl_axial_B`.
- **Pass:** ΔBz(3.5→2.0 mm) **≥ 20 mT AND ≥ 200 LSB AND ≥ 50× noise**; hard-stop field **< 130 mT
  (never clips) and ≤ 0.8× range**; measured B(z) tracks `cyl_axial_B` within **± 15 %**.
- **Also record (confirms the guess):** the field at the as-built rest gap — expect ~19 mT, and it
  must sit low-mid range (10–40 mT) so both rest and hard-stop stay unclipped.
- Gates: `test_the_full_plunge_dwarfs_the_noise_and_the_lsb`, `test_the_hard_stop_does_not_clip_the_sensor`.

### T2 — Spring rate & snap (dome only) → confirms the key feel and the FDM floor
Push each dome's centre with the force gauge to 1.5 mm, logging force vs displacement; note any
buckling snap. Repeat per (t, a).
- **Pass:** actuation force at 1.5 mm travel in **[0.12, 0.30] N** (soft enough to be comfortable,
  firm enough to return); the dome **returns to within 50 µm of rest** on release.
- **Record (not predicted — the model sizes the membrane, not the snap):** snap force/displacement,
  and **which (t, a) printed without gaps** at your nozzle. Printability is a pass/fail of its own.
- Gate: the k = 130 N/m target (`flexure.spring_rate`, `flexure.dome`).

### T3 — Five-direction signal & discriminability (full cradle) → confirms `CRADLE_LEVER`
On the assembled cradle (magnet on dome over Hall, on the PA seat), drive each of the five actions —
click (plunge) and forward/back/left/right (tilt) — to full travel and record (Bx, By, Bz). Build the
5×3 template from the measured means; then run a **live confusion matrix**: ≥ 10⁴ real presses across
the five directions, classified nearest-template.
- **Pass:** weakest direction **|ΔB| ≥ 2 mT AND ≥ 10× noise**; **min pairwise angle ≥ 25°**;
  **0 misclassifications** on the live 10⁴+ presses (predicted 0 at 10⁵).
- **This is where `CRADLE_LEVER` is measured** — the transverse field per mm of tilt travel. If the
  weakest lateral misses 2 mT, the real lever is below the 0.7 guess and the geometry needs the tilt
  amplified (a taller crown / longer lever), which this coupon quantifies.
- Gates: `test_the_weakest_direction_still_clears_the_noise`, `test_the_five_directions_are_mutually_discriminable`.
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

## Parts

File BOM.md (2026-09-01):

# ExoKey — Bill of Materials (BOM)

This Bill of Materials specifies all hardware, raw stock, fasteners, and off-the-shelf components required to build one complete **ExoKey Wearable Musculoskeletal Keyboard Carrier**.

---

## 1. Modular Carbon Fiber Space-Frame & Joint Hardware

| Qty | Part Description | Specification | Recommended Source / Part No. |
| :---: | :--- | :--- | :--- |
| **2 packs** (20 pcs) | **Hardened Steel Ballstuds (⌀ 4.8 mm)** | ⌀ 4.8 mm ball, M3 × 5.0 mm threaded shank, black oxide steel | **Yeah Racing YA-0562** (Modelsport UK / 1/10 RC) |
| **1 pc** (~0.5 m) | **Primary Central Spine Tube** | ⌀ 8.0 mm OD × ⌀ 6.0 mm ID pultruded high-modulus carbon fiber tube | Carbon fiber tube stock ($E \ge 180\text{ GPa}$) |
| **1 pc** (~0.5 m) | **Transverse Knuckle Arch & Thumb Tube** | ⌀ 6.0 mm OD × ⌀ 4.4 mm ID pultruded carbon fiber tube | Carbon fiber tube stock ($E \ge 180\text{ GPa}$) |
| **1 pc** (~1.0 m) | **Phalanx Outrigger Boom Tubes** | ⌀ 5.0 mm OD × ⌀ 3.4 mm ID pultruded carbon fiber tube | Carbon fiber tube stock ($E \ge 180\text{ GPa}$) |
| **1 sheet** (100×150 mm) | **Dogbone Clamp Plate Stock** | $2.0\text{ mm}$ (or $2.5\text{ mm}$) 6061-T6 or 7075-T6 aluminum flat plate | Metal stockists / eBay |
| **20 pcs** | **M3 Knurled Threaded Inserts** | M3 internal thread, ⌀ 4.0–4.2 mm OD, 4.0–5.0 mm length (brass) | Standard brass heat-set / epoxy inserts |
| **10 pcs** | **Pinch Clamping Screws** | M2.5 × 8.0 mm (or 10.0 mm) ISO 4762 Grade 12.9 / Stainless Socket Cap | Fastener supplier |

---

## 2. Keywells & Sensor Electronics

| Qty | Component | Specification | Notes |
| :---: | :--- | :--- | :--- |
| **5 units** | **Svalboard 5-Way Key Clusters** | 5 discrete magnetic tactile switches per cluster (Center Plunge + 4 Directional Paddles) | Svalboard Open Hardware / DataHand compatible |
| **1 pc** | **Microcontroller Board** | Seeed Studio XIAO nRF52840 (BLE 5.0, USB-C, LiPo charger) | Mounts in dorsal saddle / wrist electronics housing |
| **1 pc** | **LiPo Battery** | $3.7\text{ V}$, $150\text{–}300\text{ mAh}$ ultra-thin pouch battery with JST-PH2.0 | Provides 40+ hours continuous wireless BLE typing |
| **1 spool** | **Flexible Micro-Harness Ribbon** | 30 AWG ultra-flexible silicone ribbon cable (VDD, GND, SDA, SCL) | Routes along dorsal carbon tubes into wrist housing |

---

## 3. Ergonomic Chassis & Anatomical Strap

| Qty | Component | Specification | Fabrication Method |
| :---: | :--- | :--- | :--- |
| **1 pc** | **Dorsal Metacarpal Saddle Anchor** | Conformal anatomical saddle plate matching dorsal 3rd metacarpal bed | 3D Printed in CF-PA12 (SLS / FDM) or CNC milled |
| **1 pc** | **4-Way Middle Knuckle Manifold Hub** | 4-port cross-fitting hub (Spine + Arch + MCP3 outrigger) | 3D Printed in Titanium / SLS CF-PA12 or CNC machined |
| **1 pc** | **Circumferential Tension Strap** | $20\text{–}25\text{ mm}$ wide soft elastic TPU or silicone-lined Velcro webbing | 95-Shore A TPU 3D print or medical-grade band |

---

## 4. Consumables & Assembly Tooling

* **Structural Epoxy Adhesive:** 3M Scotch-Weld DP420 (or high-strength Araldite) for bonding M3 brass inserts inside carbon fiber tube ends.
* **Friction Paste / Loctite:** Loctite 243 (medium threadlocker) for M2.5 dogbone pinch screws; optional diamond friction gel for extreme ball grip.
* **CNC Tooling for Dogbone Clamp Milling:**
  * ⌀ 2.05 mm & ⌀ 2.7 mm drill bits.
  * ⌀ 4.76 mm (3/16") or ⌀ 4.8 mm ball-nose endmill (or $90^\circ$ spot/chamfer tool) for ball pockets.
  * ⌀ 3.175 mm (1/8") or ⌀ 2.0 mm flat carbide endmill for profile contouring.

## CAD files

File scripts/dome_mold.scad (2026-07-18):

// ExoKey silicone dome mold -- COUPON.md. Cast a soft dome (the native keypad-rubber technology).
// Cavity (bottom) + core (top). Pour two-part silicone into the cavity, press the core (pins align
// it), clamp, cure, demold, trim flash. The wall t is set by the mold GAP, not by print luck.
// Export:  -D 'part="cavity"'  /  -D 'part="core"' .  "section" shows the seated pair, cut, to check t.
part = "both";          // "cavity" | "core" | "both" | "section"

a     = 6;              // dome base radius (mm)
h     = 2;              // dome rise
t     = 0.6;            // shell wall -- silicone, thicker than TPU is fine
rim_w = 3;              // skirt width
rim_d = 1.2;            // skirt thickness
D     = 34;             // mold outer diameter
Hc    = 12;             // cavity height
Ht    = 9;              // core body height
pin_d = 2.0;            // alignment pins
vent  = 1.2;            // apex air-escape / fill hole
$fn   = 160;

Rout = (a*a + h*h) / (2*h);     // outer (dome-convex) sphere radius
zc   = Rout - h;                // its centre, above the rim plane z=0
Rin  = Rout - t;                // inner sphere -> uniform normal wall t
pinx = D/2 - 4;

module cavity() {
  difference() {
    cylinder(h = Hc, d = D);
    translate([0,0, Hc + zc]) sphere(r = Rout);                          // dome-outer bowl at the top
    translate([0,0, Hc - rim_d]) cylinder(h = rim_d + 1, d = 2*(a+rim_w)); // annular skirt recess
    for (s = [-1,1]) translate([s*pinx, 0, Hc - 4]) cylinder(h = 5, d = pin_d + 0.25); // pin holes
  }
}

// core in PRINT orientation: flat seating face at z=0, bump protruding DOWN (-z), body up (+z).
module core() {
  union() {
    difference() {
      union() {
        cylinder(h = Ht, d = D);                                        // full-width presser (covers the pins)
        intersection() {                                                // dome-inner bump, protruding down
          translate([0,0, zc]) sphere(r = Rin);
          translate([0,0, -(h+2)]) cylinder(h = h + 2, d = D);          // keep only the z<0 cap
        }
      }
      translate([0,0, -(h+2)]) cylinder(h = Ht + h + 4, d = vent);      // apex vent up the axis
    }
    for (s = [-1,1]) translate([s*pinx, 0, -3.8]) cylinder(h = 3.8, d = pin_d);  // alignment pins, point down
  }
}

if (part == "cavity") cavity();
if (part == "core")   core();
if (part == "both") { cavity(); translate([D + 6, 0, 0]) core(); }
if (part == "section")                                                  // seated, cut on +x to reveal the t-gap
  difference() {
    union() { cavity(); translate([0,0, Hc]) core(); }
    translate([0, -D, -5]) cube([D, 2*D, Hc + Ht + 10]);
  }

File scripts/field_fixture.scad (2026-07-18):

// ExoKey field-map fixture -- COUPON.md tests T1 (plunge) / T3 (lateral).
// Fix the Hall, slide the magnet over it in X (a caliper sets X), hold the gap; log (Bx,By,Bz).
// Export one part at a time:  openscad -D 'part="base"'  /  -D 'part="sled"'
part = "both";          // "base" | "sled" | "both"

gap     = 3.5;          // magnet face -> Hall chip (mm). VERIFY with a feeler gauge, tune to your board.
hall_l  = 15;           // Hall breakout pocket L,W,depth -- SET to your breakout.
hall_w  = 13;
hall_d  = 2.0;
mag_d   = 3.0;          // magnet diameter
mag_t   = 1.0;          // magnet thickness
sled_w  = 12;
sled_l  = 16;
sled_h  = gap + mag_t + 2;
wall    = 2;
clr     = 0.3;
railz   = 5;
base_l  = 60; base_w = 30; base_h = 6;
chan_w  = sled_w + 2*clr;
$fn = 72;

module hall_base() {
  difference() {
    union() {
      cube([base_l, base_w, base_h]);
      translate([0, base_w/2 + chan_w/2,        base_h]) cube([base_l, wall, railz]);  // +y guide rail
      translate([0, base_w/2 - chan_w/2 - wall, base_h]) cube([base_l, wall, railz]);  // -y guide rail
      translate([0, base_w/2 - chan_w/2 - wall, base_h]) cube([wall, chan_w + 2*wall, railz]); // x=0 datum stop
    }
    translate([base_l/2 - hall_l/2, base_w/2 - hall_w/2, base_h - hall_d])
      cube([hall_l, hall_w, hall_d + 0.3]);                                            // Hall pocket
    translate([base_l/2 - 2, base_w/2 + hall_w/2, base_h - hall_d])
      cube([4, base_w/2, hall_d + 0.3]);                                               // wire slot out +y
  }
}

module magnet_sled() {
  difference() {
    cube([sled_l, sled_w, sled_h]);
    translate([sled_l/2, sled_w/2, gap])  cylinder(h = sled_h, d = mag_d + 0.15);      // magnet slot (top-load, rests at z=gap)
    translate([sled_l/2, sled_w/2, -0.1]) cylinder(h = gap + 0.2, d = mag_d - 0.8);    // window to the Hall
  }
}

if (part == "base" || part == "both") hall_base();
if (part == "sled" || part == "both") translate([base_l/2 - sled_l/2, -sled_w - 6, 0]) magnet_sled();

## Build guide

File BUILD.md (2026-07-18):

# Building an ExoKey

> **Status: nothing here has been built.** ExoKey is a research project that designs a
> wearable keyboard by simulation. The printed *structure* is real and printable today; the
> *working device* is not — it has no firmware and no proven electronics yet. This page is the
> honest path from "I own a 3D printer" to "I have the parts in hand," and it is clear about
> where the road currently ends. For the science and the full record, see
> [VISION.md](VISION.md); for the parts, [BOM.md](BOM.md).

## What it is

A keyboard you wear on the back of one hand. Instead of pressing keys on a desk, each
**fingertip sits in a little cup** and can push in one of **five directions** — like a tiny
joystick per finger. Five fingers × five directions is enough to type QWERTY by chords. The
cups are carried on a lightweight printed lattice — the **gauntlet** — that arches over the
back of your hand and is held on by a soft **strap**. You can stand up and walk away wearing
it.

The unusual thing about the design is *how* it was made: the shape was **grown by an
optimiser** that co-simulates the device together with a model of the hand's muscles, so the
structure comes out looking like a bone rather than a bracket — thick where a hand must bear
it, thin everywhere else, hollow inside.

## How it works

- **The key.** Each fingertip cup holds a small **disc magnet** on a springy printed
  [flexure](#glossary). Under the cup sits a fixed **3-axis Hall sensor** that measures the
  magnetic field in x, y, z. Push the fingertip and the magnet moves; the field shifts in a
  direction the firmware can tell apart from the other four. No switches, no contacts — just a
  magnet moving over a sensor.
- **The structure.** The [gauntlet](#glossary) is a lattice of hollow printed tubes. It is
  [touch-limited, not load-limited](#glossary): the tubes are as thick as they are because a
  *hand* has to be able to bear against them without a sharp edge (a 1.5 mm minimum radius),
  not because the forces are large. Being over-stiff for its load is exactly why it can be
  hollow for free.
- **The strap.** A webbing band pulls the gauntlet down onto the hand with about 1 newton.
  It is not optional — without it the frame springs away from the hand many times too far.
- **The read-out (firmware).** Boot, learn the resting field, then scan ~500 times a second,
  compare each sensor's field to a calibrated map of its five directions, debounce, and send
  the resulting keystrokes over Bluetooth. **This firmware is designed on paper but not
  written** — see [What is not done yet](#what-is-not-done-yet).

## Print it

**Easiest path — just print the structure:** download `gauntlet.stl` from the project's
**[GitHub Releases](https://github.com/GlassOnTin/exokey/releases)** and slice it. You do not
need Python, the simulator, or any of this repo to print that file.

**Print settings** (these are baked into the geometry — the part is *designed* to print this
way):

| Setting | Value | Why |
|---|---|---|
| Nozzle | 0.4 mm | The tube walls are two perimeters of a 0.4 mm nozzle. |
| Perimeters / walls | **2** | |
| Infill | **0%** | The tubes are meant to be **hollow** — 2 walls + 0% infill is what makes them so (~40 g instead of solid). |
| Orientation | **standing on the wrist, fingers pointing up** | Chosen by the optimiser to need no prop supports. |
| Supports | **none** | Overhangs stay under 45° and bridges under 10 mm by construction. |
| Material | CF-PA12 (SLS) or a stiff FDM filament | The mass/strength figures assume CF-PA12; any stiff filament prints. |

Print the **five TPU cradles** separately in flexible TPU (they are the moving keys). Their
~0.32 mm spring membrane is at the limit of a 0.4 mm nozzle — a **0.25 mm nozzle** helps.

**Fit it to your hand:** the shipped `gauntlet.stl` is sized to the *median* (185 mm) hand. To
print your size, install the tools (below), download the design files (`final_design.pkl` and
`bone.npz`) from the Release, and run:

```bash
make fit MM=192        # your hand length, wrist crease to middle-fingertip, in millimetres
# -> out/gauntlet_192mm.stl
```

This re-fits the finger cups and the frame to your hand. It is a **first-order fit**: the cups,
sensor seats, and frame all scale together, but the component pockets (Hall sensor, magnet,
XIAO) stay at true size, and the *topology* of the skeleton is still the one optimised across
the whole population — a fully re-optimised skeleton for your exact hand means re-running the
search (`make optimise`, hours). The strap buckle and the wells' adjustment cover the rest.

## Assemble it

Assembly is **modelled geometrically but never performed.** What the model guarantees: every
finger can **slide into** its cup along a clear entry route, and its pad **seats** on the cup
floor (both are gated by tests). What does not exist as instructions: a step-by-step build, an
exploded view, or wiring. In outline: press a magnet into each TPU cradle; drop each cradle
into its well; seat a Hall breakout in the pocket under each well; route the 4-wire bus
(power + I²C) along the dorsal grooves to the XIAO + battery in the wrist housing; thread the
strap through the lugs. **Do not treat this as a tested procedure.**

## Get the tools (only if regenerating or resizing)

```bash
git clone --recurse-submodules https://github.com/GlassOnTin/exokey
cd exokey
make deps          # venv + pinned deps (requirements.txt) + the MyoHand submodule
make test          # the gates -- run the suite; each one caught a real bug (~5 min)
make stl           # regenerate out/gauntlet.stl (median hand) from the shipped design
make fit MM=192    # or your size
```

`make` hides the `PYTHONPATH=. OMP_NUM_THREADS=1` prefixes every script needs. Run `make` with
no target for the list. `make stl`/`fit` need the design files (`final_design.pkl`, `bone.npz`)
— they ship on the Release; a fresh clone does not have them, and producing them from scratch
is the expensive `make optimise` step (the cloud burst in [`cloud/hetzner.sh`](cloud/hetzner.sh)
exists for exactly that).

## What is not done yet

The structure is the finished part of this project. These are **not**:

- **Firmware.** Outlined only (`VISION.md §8.15l qqq`). No code, no BLE HID, no
  direction→QWERTY map. The device cannot type until someone writes it.
- **Electronics / PCB.** No board design. The Hall sensors sit on generic breakouts in carved
  pockets; the "harness" is a wire-routing plan, not a schematic.
- **The read-out is a prediction, not a measurement.** The magnetic figures and the spring
  come from a numpy model; the rest gap (3.5 mm) and the cradle lever (0.7) are guesses. The
  planned next physical step is a **stage-1 coupon** — TPU domes across a thickness/radius
  band, a printed seat, and a TLV493D breakout — measured against thresholds set in advance
  (`VISION.md §8.15l rrr`). Until that coupon exists, treat [BOM.md](BOM.md) as provisional.
- **Per-user fit** is first-order only (see above).

## Glossary

- **Gauntlet** — the printed lattice that arches over the back of the hand and carries the
  finger cups. The "bone."
- **Well / cup** — the cavity a fingertip sits in; its floor is what a downward press pushes
  against.
- **Flexure** — a part that bends *instead of* using a hinge or spring. Here, a thin printed
  TPU dome that returns the fingertip key to rest.
- **Thenar group** — the muscles at the base of the thumb (ADP, FPB, APB). The stock hand
  model lacks the adductor, so its thumb literally cannot press a key; adding this group is
  what makes the thumb work.
- **Effort (Σaᵢ³)** — how the model scores exertion: the sum of each muscle's activation
  cubed (the Crowninshield–Brand criterion). Lower is more comfortable.
- **Touch-limited vs load-limited** — a structure sized by what a *hand can bear against
  without pain* (a 1.5 mm minimum radius) rather than by the *forces* it carries. ExoKey is
  touch-limited, which is why it can be hollow.
- **Wolff's law** — bone grows where it is loaded and thins where it is not; the optimiser
  does the same to the lattice.
- **Entry-first mount** — a cup designed so the finger's slide-in route is kept clear *first*,
  and everything else fits around it.
- **Trabecular** — the spongy, strut-like internal pattern of real bone; the grown lattice
  resembles it.

## Errata (numbers that disagree across the repo)

- **Gate count.** The `README` historically said "109" and `VISION.md` said "57"; the suite
  currently collects **139**. `make test` is the authoritative, live count.
- **Stale file names.** `VISION.md §8.15l` cites `manufacture/wellmod.py`, `scripts/coupon.py`,
  and `tests/test_wellmod.py` — none of which exist. Their logic was consolidated into
  `manufacture/readout.py`, `manufacture/mount.py`, and `manufacture/entry.py` (tested by
  `tests/test_readout.py`, `tests/test_mount.py`, `tests/test_entry.py`). The flexure test
  coupons (`out/coupon_*.stl`) ship on the Release, but their generator script was not
  committed.

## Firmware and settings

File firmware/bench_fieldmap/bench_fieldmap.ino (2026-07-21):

/*
 * ExoKey bench field-map firmware  --  COUPON.md tests T1 (plunge) / T3 (lateral).
 *
 * Streams the raw 3-axis field (Bx, By, Bz) from one TLV493D over USB serial as CSV, so a
 * caliper-stepped magnet can be logged straight to a file and dropped into the T1/T3 tables.
 *
 *   Board:    Seeed XIAO nRF52840  (FQBN Seeeduino:nrf52:xiaonRF52840). 3.3 V, native-USB serial.
 *   Sensor:   TLV493D-A1B6, I2C.  Wire: VCC->3V3, GND->GND, SDA->D4, SCL->D5.  (Pull-ups are on
 *             the breakout; a bare chip needs 4.7-10 kOhm SDA/SCL pull-ups + a 100 nF cap.)
 *   Library:  Arduino Library Manager -> "XENSIV 3D Magnetic Sensor TLx493D" (Infineon).
 *   Output:   CSV "t_us,Bx_mT,By_mT,Bz_mT".  Lines starting with '#' are info -- skip them.
 *             LSB conversion: counts = mT / 0.098  (the model's HALL_LSB).
 *
 * NOT hardware-tested -- compiled against the library, but verify on the bench. Single sensor; for
 * the 5-sensor device wrap each read in a TCA9548A channel select (see docs/electronics.md). The
 * XENSIV library also drives the device's TLI493D-W2BW -- swap the class to TLx493D_W2BW there.
 */
#include <Wire.h>
#include "TLx493D_inc.hpp"
using namespace ifx::tlx493d;

#define AVERAGE   8         // samples averaged per output line -- cuts the ~0.2 mT noise by ~sqrt(N)
#define I2C_HZ    400000    // fast-mode I2C

TLx493D_A1B6 dut(Wire, TLx493D_IIC_ADDR_A0_e);

void initSensor() {
  dut.begin(false, false, false, true);       // no power-pin (always-on single sensor), run init
  Wire.setClock(I2C_HZ);
  dut.setSensitivity(TLx493D_FULL_RANGE_e);   // +-130 mT so the 61-80 mT plunge/hard-stop never clips
}

// Unstick a TLV493D-A1B6 holding SDA low (its known bus-lock): clock out 9 SCL pulses + a STOP so the
// slave releases, then reset+re-init. Layer 1 of the recovery in docs/electronics.md.
void i2cRecover() {
  Wire.end();
  pinMode(SCL, OUTPUT);
  pinMode(SDA, INPUT_PULLUP);
  for (int i = 0; i < 9; i++) {
    digitalWrite(SCL, LOW);  delayMicroseconds(5);
    digitalWrite(SCL, HIGH); delayMicroseconds(5);
  }
  pinMode(SDA, OUTPUT);                        // manual STOP: SDA low->high while SCL high
  digitalWrite(SDA, LOW);  delayMicroseconds(5);
  digitalWrite(SDA, HIGH); delayMicroseconds(5);
  Wire.begin();
  Wire.setClock(I2C_HZ);
  dut.reset(true, false);                      // A1B6 reset
  initSensor();
}

void setup() {
  Serial.begin(115200);     // native USB CDC -- baud is nominal, throughput is USB-limited
  unsigned long t0 = millis();
  while (!Serial && millis() - t0 < 3000) { }  // wait up to 3 s for a monitor, then run headless
  initSensor();
  Serial.print("# ExoKey bench field-map -- TLV493D, 0.098 mT/LSB, average=");
  Serial.println(AVERAGE);
  Serial.println("# hold the magnet still at each caliper step; let it settle, then move on.");
  Serial.println("t_us,Bx_mT,By_mT,Bz_mT");
}

void loop() {
  double sx = 0, sy = 0, sz = 0;
  int n = 0;
  for (int i = 0; i < AVERAGE; i++) {
    double x, y, z;
    if (!dut.getMagneticField(&x, &y, &z)) {   // false -> read failed
      Serial.println("# i2c error -- recovering");
      i2cRecover();
      return;                                  // drop this line; loop() retries
    }
    sx += x;  sy += y;  sz += z;               // mT
    n++;
    delay(2);
  }
  if (n == 0) return;
  Serial.print(micros());   Serial.print(',');
  Serial.print(sx / n, 3);  Serial.print(',');
  Serial.print(sy / n, 3);  Serial.print(',');
  Serial.println(sz / n, 3);
}

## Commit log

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2026-07-12 cloud: 'burn' subcommand — run, fetch, then delete the box
    A powered-off Hetzner Cloud server bills exactly the same as a running one; only
    deleting stops the meter. Forgetting to delete is the only way a burst machine gets
    expensive, so wire the teardown to the run instead of leaving it to memory. The trap
    fires on crash and interrupt too, so a failed run cannot leave a box billing.
    Also record the measurement: a 16-vCPU shared box (cpx62) beat an 8-vCPU dedicated one
    (ccx33) by 2.3x for the same money on this workload.
2026-07-13 Model the well as a cradle, add adductor pollicis, enforce equilibrium
    Three defects, each of which invalidated the results above it.
    1. THE EQUILIBRIUM RESIDUAL WAS NEVER CHECKED.
    solve_activations does not enforce equilibrium. It least-squares-fits the
    required joint torque, pins the demand to the closest ACHIEVABLE torque, and
    returns the shortfall as `residual`. No caller had ever read it. Measured on
    the shipped design, the muscles failed to balance the load by 14-62%.
    Worse, the error was self-reinforcing: an action a digit cannot perform yields
    a small achievable torque, hence small activations, hence LOW EFFORT. Impossible
    actions looked CHEAP, so best_action_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
2026-07-13 VISION §3: regenerate the measured table; it still asserted retracted claims
    §5 retracted "the five directions differ by 1.9 million x" and "click is the
    cheapest action everywhere" -- but §3 went on stating both as measured fact, so
    the document argued with itself. Regenerated from the current model instead of
    hand-editing numbers.
    What the table now says, and each part is a design decision:
    - the THUMB can perform NOTHING (no adductor). No characters go under it.
    - left/right mostly FAIL for middle, ring and little: the interossei are weak.
    That is a prediction of the muscle model, not a tuned outcome.
    - what survives is exactly click/forward/back on four fingers = three row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
2026-07-13 Open up the layout: the thumb carries space, and price the pointer
    THE THUMB WAS IDLE AND SPACE WAS NOT SCORED AT ALL. Two errors compounding.
    The thumb has five performable directions and is the CHEAPEST digit on the hand,
    doing nothing -- while the LITTLE FINGER, the weakest digit there is, carried three
    QWERTY rows. That was invisible while the model believed the thumb could not press.
    And SPACE, the most frequent keystroke in English, did not appear in the objective.
    It is ~18 per 100 letters, and the left hand's 15 QWERTY letters are only 58.7 of
    those 100 -- so SPACE IS ~22% OF THE LEFT HAND'S ENTIRE KEYSTROKE LOAD, bigger than
    any letter, bigger than 'e'. The objective was missing i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
2026-07-13 The palm is a cup, not a plate -- and the obvious arch fix does not work
    "Invert the support structure -- it doesn't follow the natural shape of the hand."
    Correct, and the hand says so. Measured off the metacarpal meshes: the palm is a CUP
    6.4 mm deep, edges protruding palmar and the middle HOLLOW (the transverse metacarpal
    arch). build_body bolts FOUR CORNERS OF A FLAT RECTANGLE across it at one depth, so
    they either float off the eminences or dig into the hollow.
    The obvious fix is an ARCH, and the physics argues for it: a keypress pushes the body
    DORSALLY, INTO the palm, so an arch convex toward the palm takes that in COMPRESSION
    where a plate takes it in BENDING.
    THE MEASUREMENT REFUS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
2026-07-13 Shell elements: the beam model was wrong about the arch by 25x
    structure/shell.py -- MITC4 shells (PyNite add_quad), which carry MEMBRANE action.
    That is precisely what an arch uses and precisely what a stick figure of beams does
    not have.
    THE GATE FIRST, same discipline that validated the beam model against a closed-form
    cantilever: a simply-supported square plate, w = 0.00406 q a^4 / D (Timoshenko). It
    CONVERGES -- 2.3% -> 1.9% -> 1.0% -> 0.7% as the mesh refines. A shell that cannot
    reproduce a textbook plate has no business being asked about an arch.
    WHAT IT SETTLED:
    beam model shell model
    arch mass penalty +212% +8.4%
    arch stiffness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
2026-07-13 "It gets in the way": a hugging frame must be a SHELL, not sticks
    THE USER'S ARGUMENT, and it is the best one made about this device:
    "having the supporting structure far from the hand is a problem because it
    gets-in-the-way of me using my hands. If the supporting structure hugs the hand
    and stays above the sensors as much as possible it becomes more a natural
    extension, rather than holding a big ball."
    MEASURED, AND THEY ARE RIGHT. Of build_body's structural nodes, 15 OF 16 ARE PALMAR
    of the hand, standing off it by a mean of 27 mm and a MAXIMUM OF 68 mm. The palm is
    the WORKING SURFACE of the hand -- that is the volume you use to hold a cup, a pen, a
    door handle. The device is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
2026-07-13 The gauntlet: anchor points and boundary conditions FIRST
    "What we need is the anchor points and boundary conditions first."
    Right, and it was worth more than every optimisation run in this project put
    together. Three boundary-condition errors, each of which flattered the answer:
    1. IT IS NOT BOLTED TO A WALL. The first gauntlet used RIGID supports, which absorb
    the keypress for free. With honest soft-tissue anchors the deflection was 7x worse
    and it FAILED the gate at every thickness -- including 2 mm and 70 g.
    2. THE ANCHOR WAS A HINGE. The supports were the proximal RING of the metacarpal
    shells: a LINE of nodes with ZERO extent along the lever. A keypress at a fingertip
    12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
2026-07-13 A flesh model to go with the bones: tissue measured from MRI
    "I think we need to find a flesh model to go with the bones."
    It was the load-bearing gap. MyoHand ships BONES and crude flesh CAPSULES -- and over
    the CARPUS, exactly where a gauntlet anchors, NO FLESH AT ALL. So WRIST_TISSUE was a
    GUESS (3 mm) and it set the stiffness of the whole structure's main anchor.
    THE SOURCE, and why not the obvious one:
    PIANO hand-MRI dataset Apache-2.0 USED. 50 volumes + bone masks + muscle masks.
    NIMBLE (built on it) AVOIDED. Code is MIT but LICENSE.md is the UNEDITED GITHUB
    TEMPLATE ("Copyright (c) 2011-2024 GitHub Inc."),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
2026-07-13 Fit the gauntlet to the SKIN, and three bugs that hid behind a coarse mesh
    The gauntlet's domain was built at capsule_radius + hug. A capsule is a circular
    tube; a hand is not. The metacarpals are flat and the fingers oval, so a shell
    fitted to a tube stands proud of the flats and bites into the sides. And a
    capsule is not skin: the MRI tissue is 4.8-6.8 mm dorsally, about twice what
    MyoHand's capsules imply, so the "4 mm standoff" had the shell inside the hand.
    The ring radius is now taken PER DIRECTION off the skin surface itself, and the
    standoff is finally enforced against the assembled skin -- which is the only
    thing that can see a NEIGHBOURING digit. The anchor patch bears on skin too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
2026-07-13 Grow the gauntlet on a free-form domain, and stop hanging it from a force nothing supplies
    THE DOMAIN. The gauntlet's design space was a structured quad grid -- half-shells over
    each metacarpal, rails over each finger. ESO could only delete quads from that grid: it
    could not put a strut where the grid had none, route a diagonal across the dorsum, or
    brace one finger against the next. Whatever it deleted, the answer was always some subset
    of five rails and four shells. The optimiser was not finding rails; it was never offered
    anything else.
    structure/lattice.py replaces it with a ground structure: a dense lattice of candidate
    bars filling the whole shell of space the gauntlet may occupy, two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
2026-07-13 Co-optimise the layout WITH the gauntlet, and fix the load case that was never real
    THE CO-DESIGN. The layout decides where the buttons go and which directions are wired; the
    gauntlet decides what it costs to hold them steady. Those were never in the same loop: the
    GA optimised postures against a box bolted to the palm, and the bone structure was grown
    afterwards against whatever it was handed. opt/run.py now scores every design by the
    gauntlet it would need.
    THE LOAD CASE WAS FICTION, and the user's question ("why do we have elements that carry no
    load, and others high load") is what exposed it. Two answers:
    * MOSTLY WE DON'T. Only 1 of 434 struts is idle; 309 carry 1-10% of the peak. T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
2026-07-13 Give the palmar-box tests their own dimensions
    The box is no longer a design vector -- six variables were deleted with it -- but
    structure/frame.py is still real physics and these four tests still teach real lessons
    (shell vs beam by 25x, the floor legs reaching distinct feet, where the compliance
    lives). They just have to state the box's dimensions themselves rather than read them
    out of a design vector that has stopped describing one.
    83 pass. The previous commit's message claimed 83 pass while 4 were failing; it was
    wrong when it was written.
2026-07-13 Co-optimise the front, and let the nodes drift -- but report what that actually buys
    THE RUN. 40 generations, 2400 evaluations, 61.8 min on a cpx62. Every evaluation GROWS a
    gauntlet (coarse); the front is then re-grown at full resolution to be reported. 15 feasible
    non-dominated designs, no cornered variables. Knee: 14419 candidate struts -> 316, 5.1 g of
    bone, buttons 485 um against the 500 um gate, strap 1.00 N.
    BONE 6.4-8.7 g across the front. ADJUSTERS 21.3-24.1 g. ⚠ THE ADJUSTERS ARE 75% OF THE WORN
    MASS AND ADJUSTER_MASS IS A GUESS WITH NO MECHANISM BEHIND IT. A made-up number now dominates
    the objective we just spent all this work making real.
    THE LOAD SET IS VINDICATED: the bind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
2026-07-13 The strap only pulls where a BAND is. Everything else was leaning on thin air.
    THE USER, looking at the render: "I see that the straps are currently too far down the
    thumbs and so would restrict or load the thumb."
    Correct -- and chasing it down turned a drawing error into a modelling one.
    THE DRAWING ERROR. A band built from the hand's whole cross-section encircles the THUMB
    RAY too, and a strap across the thumb metacarpal loads the thumb on every keystroke. No
    loop around the base of the metacarpals can avoid it: the thumb is simply THERE. The wrist
    band now goes PROXIMAL of the trapezium (what a watch strap does, and why); the metacarpal
    band passes through the FIRST WEB SPACE, distal o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
2026-07-14 Pin the live render with a test: it has failed silently TWICE
    viz/live.py drew the PALMAR BOX for a whole 62-minute run (KeyError: 'alu_w'), then
    unpacked grow()'s return with the wrong arity and did it again. Both times the exception
    was caught so a render bug could not kill an hour-long optimisation -- which is right --
    and both times the 3D panel sat empty while the front streamed happily beside it.
    The user has caught nearly every real bug in this project by LOOKING. They were looking at
    nothing. The render is not decoration; it is the instrument, and it is now tested like one.
2026-07-14 A strap the structure cannot reach is not a strap
    THE USER, watching the live run: "the straps no longer appear connected to the elements?
    Is that just a rendering issue?"
    It was not. The wrist band was sitting at -31 mm -- 31 mm PROXIMAL of the hand, out on the
    FOREARM, where the gauntlet does not go -- and the structure reached it at ONE node.
    The rule was "12 mm proximal of the most proximal thumb skin", which sounds safe until you
    MEASURE where the thumb metacarpal starts: it reaches back to -2 mm, right onto the carpus.
    So the rule walked the band off the hand, and then a min() dragged it out to the proximal
    edge of the bearing patch for good measure.
    THE WINDOW IS DERIVABLE AND I GU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
2026-07-14 The strap ring was a circle I made up. Draw the hand instead.
    THE USER: "I still don't see any nodes on the wrist strap?"
    The nodes were there. The RING was not. viz/live.py drew the band as a FIXED 55 mm circle
    about the hand axis -- the hand is ~25 mm across at the wrist, so the ring floated at twice
    the radius of the hand, and the five nodes the strap actually pulls on sat well inside it.
    TWO RENDERERS, TWO GEOMETRIES. The static view computed the band from the hand's real
    cross-section; the live view invented a circle. That is exactly the divergence that produced
    the LAST bug (the picture drew a strap round the thumb while the physics pulled on
    thumb-free nodes), and I reintroduced it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
2026-07-14 FDM printability as a hard constraint on the design space
    The gauntlet now prints. 921 struts, 6.93 g in the beam model (20.3 g as the
    filleted solid), every strut at or above the 0.4 mm nozzle, 499 um at the wells
    against a 500 um gate.
    Four wrong versions of the rule, and each failed in a way that LOOKED like a
    finding about the device rather than a bug in the model:
    ban all shallow struts -> banned all shear bracing; NO structure in the
    domain met the deflection gate, at any mass
    ban un-supportable nodes -> banned all five finger wells, in every one of
    1000+ build directions. THE HAND IS NOT IN THE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
2026-07-14 Retract an overstated claim: the nozzle floor was NOT shown to make the topology chunkier
    VISION.md 8.15(a2) asserted that the minimum-feature bound is "what makes the
    answer trabecular" -- few thick graded members instead of many equal thin ones.
    That is the RATIONALE for the whole exercise, and it reads well, but this project
    has not demonstrated it and the evidence so far points the other way.
    The printable gauntlet is the SAME 921-member topology as the unconstrained one,
    fattened and re-sized. The topology was never re-derived under the floor. Every
    attempt to re-derive it produced a worse structure, and the reason is worth
    keeping: with a minimum-feature floor the sizer can no longer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
2026-07-14 Put the supports behind a toggle, and draw ALL of them
    The horizontal red lines running across the typing animation were the sacrificial
    support pillars, drawn correctly (all 179 feet land exactly on the bed plane) but
    shown in the worst possible way.
    They look horizontal because the build direction is radial: the part prints ON ITS
    SIDE, little-finger down, so the printer's vertical axis lies almost flat in a
    camera that looks at the back of the hand. Every column projects as a near-
    horizontal line straight across the render.
    Two things wrong with that as a picture:
    - it is clutter in an animation about TYPING. Now behind a "show supports"
    button, off by default.
    - it showed onl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
2026-07-14 Fix the pruner: it was halting while progress was still available
    THE USER: "fix the pruner so we can trust the 20g number."
    Four defects, all the same shape, and together they cost ~1.5x in mass and ~2x in
    support:
    1. A CUT THAT BREAKS THE GATE IS NOT A STOPPING CONDITION. It is a cut that was
    TOO BIG. The loop used to `break` the moment a re-size missed the gate, so one
    overshooting cut ended the whole run -- after FOUR steps on the fine domain.
    Now it puts the cut back, halves the rate, and tries again. Likewise a cut that
    disconnects a button.
    2. COLD RESTART. r0 was doing double duty as the stiffness REFERENCE and the
    search START, so every re-size began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
2026-07-14 Splines, spikes, and the human-factors frame
    THE USER, in order:
    "could we do some final optimisation of cubic spline elements rather than linear?"
    "My bones have no sharp edges."
    "sharp corners are not ergonomic... a keyboard needs to be 'friendly' and not
    weaponry like a knuckle duster"
    "The whole exercise is a human factors design. That's part of the appeal."
    1. CURVED LOAD PATHS (structure/spline.py). Every member was a straight chord, so
    every load path was a POLYLINE with a kink at every node: measured, 384 of the
    669 members continue a path through a node and turn a median of 31 deg there.
    The SDF fillet hid it; the centreline still kinked.
    Fixed by pairing me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
2026-07-14 The device is TOUCH-limited, not load-limited -- so make the bone hollow
    THE USER: "I think the thickness of struts should be a spline too, with a major and
    minor radius, and principal orientation as a spline."
    That idea is right, and chasing it properly produced a better finding than the idea.
    1. THE SECTION MACHINERY (structure/section.py, structure/fem.py). Iy and Iz are now
    separate and every element has a ROLL. fem.py's own docstring used to say the
    rotation about a member's own axis "does not matter -- no orientation vector to get
    wrong": true of a CIRCLE and of nothing else. Locked by a test: an oriented 2:1
    ellipse is 2x stiffer than a circle of the same MASS, and 4x st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
2026-07-14 Stray fragments, loose ends, and a renderer that drew sawn-off pipes
    THE USER, looking at the render: "There are still a few stray elements and sharp open
    ended elements."
    All three things they saw were real. Two were bugs in the STRUCTURE and one was a lie
    in the PICTURE.
    1. A STRAY COMPONENT -- 13 nodes floating completely free, touching no anchor and no
    button, carrying nothing. `connected()` keeps everything reachable from ANY anchor,
    and an anchor is merely a node that bears on the flesh -- so a fragment hanging off
    one, connected to nothing else, passed the test. The rule has to be stricter:
    THE STRUCTURE IS THE PIECE THAT HOLDS THE BUTTONS. Everything else is debris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
2026-07-14 Mobile views: the render was CROPPED, not zoomed in
    THE USER: "typing.html doesnt support pinch zoom and is too zoomed in to fit the hand
    on a landscape mobile screen."
    The diagnosis was wrong at first and the measurement corrected it.
    ⚠ IT WAS NEVER A CAMERA PROBLEM. My first fix pulled the eye back on small screens, and
    it made the hand TINY. Measured: at the SAME eye distance, in an 844 x 338 plot, the hand
    fits with room to spare -- Plotly's 3-D scene already scales to its container.
    The actual bug is one word: `responsive` is FALSE by default. The WebGL canvas keeps the
    pixel size it was FIRST created at -- a desktop one -- and a smaller div simply CLIPS it.
    The hand was not zoomed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
2026-07-14 Session close: docs, README, artefact index, and the disclosure re-anchored
    The README described the PALMAR BODY -- an architecture abandoned three sessions ago.
    The front door of the repo was advertising the wrong device.
    - README: the dorsal gauntlet, the human-factors frame, tonight's numbers, and the
    current pipeline (printable -> ergonomic -> bone -> typing_view -> export_stl).
    - VISION.md: SKIN_R and ASPECT_MAX disclosed as guesses; PLA creep and NYLON HYGROSCOPY
    recorded as in-service risks the datasheet does not show; bearing AREA named as a
    missing constraint (the wells got a cradle, the anchor feet did not).
    - VISION.md 8.15e: the SPIKE, the DEBRIS, and the BEARI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
2026-07-15 The finger-well sensor: a printed flexure, and every well is five-way
    FLEXURE (manufacture/flexure.py, scripts/flexure.py, tests/test_flexure.py)
    A 20 gf / 1.5 mm restoring spring is soft (~131 N/m). Sized across the palette,
    a stiff FDM plastic cracks (glass-nylon 50 vs 25 MPa; PLA/PETG/ASA alike) -- the
    merit is sigma_fat/E. Only TPU (a dome) or thin spring steel (a leaf) survive. And
    the plunge cannot compress (~100x too stiff), so the one-part answer is a TPU dome:
    soft in tilt and plunge, snaps for a click. TPU/PETG/ASA added to MATERIALS.
    MOMENT & LEVER (design/sensor.py, scripts/sensor.py, tests/test_sensor.py)
    Actuation effort tied to the cradle solve per finger/direction across the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
2026-07-15 Lock in the sensor, strap, and bearing shell: §8.15i and a re-anchored disclosure
    Capture the inner BEARING SHELL as IP (VISION §8.15i): the gauntlet-to-skin interface
    is an impact distributor -- a plate on the soft-tissue elastic foundation, sized by the
    KNOCK, not the strap preload (a 50 N knock is 7.1 MPa through a bare 1.5 mm foot, but
    56-86 kPa spread by a 1.5-2 mm shell) -- built as a SANDWICH with the topology-optimised
    lattice as its core, so the impact stiffness comes without doubling the mass. Sizing
    physics verified (manufacture/bearing.py, tests/test_bearing.py, 4 tests); the sandwich
    construction is proposed, pending a re-solve of the deflection gate. 107 tests pass.
    Re-ancho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
2026-07-15 Re-solve the gate with the sandwich face; prune stale renders
    The sandwich INNER FACE -- CST membrane triangles tying the bearing nodes -- is added
    to the per-element Sizer (backward-compatible: default off reproduces the 498 um bone
    gate exactly). Re-solved at the bone's real sections, the buttons hold at 485 um <= the
    500 um gate, so the face does not compromise key-crispness. It barely helps the gate
    (-3%, the anchor is tissue-dominated), which confirms its value is IMPACT (8.15i), not
    crispness. The membrane model captures the in-plane tying and the gate, not the
    out-of-plane plate bending that is the impact benefit, and the +10.8 g face mass is a
    full-membrane upper bound -- the sandwic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
2026-07-15 Decision: the gauntlet mounts on the OUTSIDE of the strap (§8.15j); re-anchor
    The design iteration the render prompted: put the gauntlet on the OUTER face of the
    soft TPU strap, so the strap is the only thing that touches the hand -- cushion, tension
    tether, and load-spreader in one part, attached by loops printed into the strap itself.
    Re-solved (scripts/onstrap.py): the 500 um gate holds at 499 um (+0%) with the soft strap
    in the load path, because TPU is stiffer in through-thickness compression than the soft
    tissue. This supersedes the inner bearing shell (§8.15i) as the skin interface, with a
    forward-note on §8.15h/i. Renders: scripts/onstrap_view.py (out/onstrap.html, the new
    layerin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
2026-07-18 coupon: dome generator + printable bench rig (field-map fixture, silicone dome mold)
    The flat TPU membrane measured ~230 g at 1.5 mm (target 20 g) -- too stiff; it
    stretches rather than bends. So this adds the softer flexures and the rig to
    measure the read-out for real.
    - scripts/coupon.py: dome() -- a shallow spherical-cap coupon (rolls/snaps
    instead of stretching), sweeps apex rise h in {1,2,3} mm.
    - scripts/field_fixture.scad: the T1/T3 field-map fixture (Hall base + magnet
    sled). Decouples the SIGNAL (rigid magnet vs Hall, caliper sets X) from the
    flexure, so the bench needs only a caliper + micrometer.
    - scripts/dome_mold.scad: a two-part silicone dome mold (cavity + core). Cast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
    [dome_mold.scad, field_fixture.scad]
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2026-07-21 firmware: bench field-map sketch for the XIAO nRF52840 (the repo's first firmware)
    firmware/bench_fieldmap/bench_fieldmap.ino streams raw 3-axis field (Bx,By,Bz) from a TLV493D over
    USB serial as CSV, so a caliper-stepped magnet logs straight into the COUPON.md T1/T3 tables. Built
    on the Infineon XENSIV TLx493D library (which also drives the device's TLI493D-W2BW); 8-sample
    averaging to beat the noise, and the I2C bus-lock recovery from docs/electronics.md. Compile-clean
    for Seeeduino:nrf52:xiaonRF52840 (76.5 KB, 9% of flash); not yet hardware-tested.
    - README.md: a "Build -- beyond the structure" section (coupon/rig 3D prints + the firmware
    toolchain: arduino-cli core/lib install, compil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
    [bench_fieldmap.ino]
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
